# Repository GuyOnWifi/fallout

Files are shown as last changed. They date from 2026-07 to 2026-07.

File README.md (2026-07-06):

# Soup Sports

Nothing like spending your last days on Earth soup! I mean just look at him!! 

## Inspiration

We loved the Wii Sports minigames, but unfortunately as a child, we were only able to play them at that rich friend's house. But now, in the hardware capital of the world, we're able to get microcontrollers tens of times more powerful for dirt cheap. So we thought... why not make a dirt cheap and dead simple Wii Sports controller? 

## What is it? 

It's really just a Xiao ESP32-C3, an MPU 6050 in a wristband form factor. It also has a dongle to receive the wireless transmission! 

## Minigames

### Boxing

Fight soup

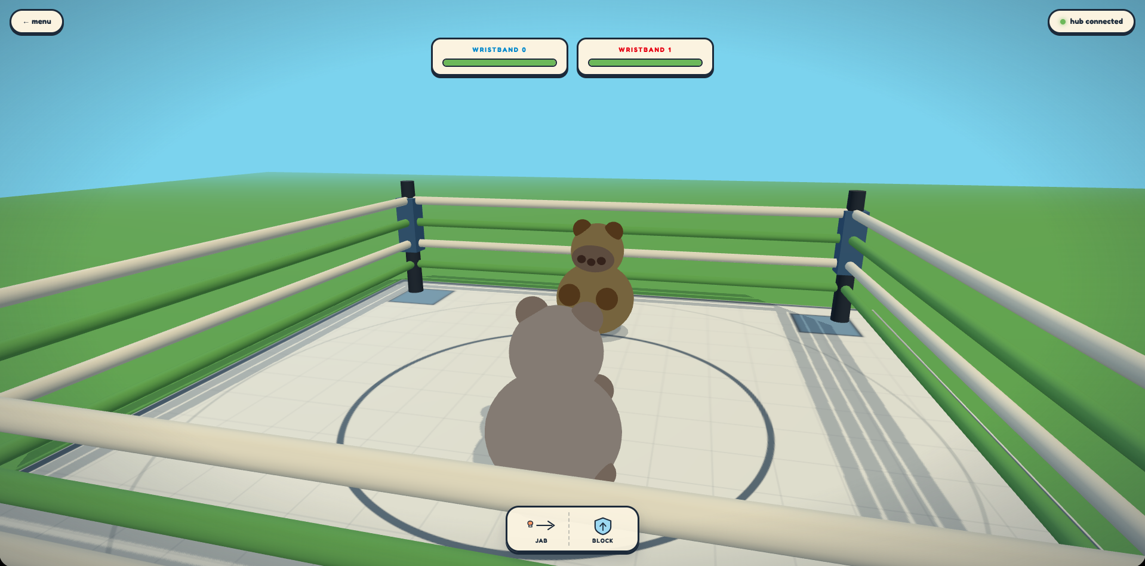
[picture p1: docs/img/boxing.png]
Boxing


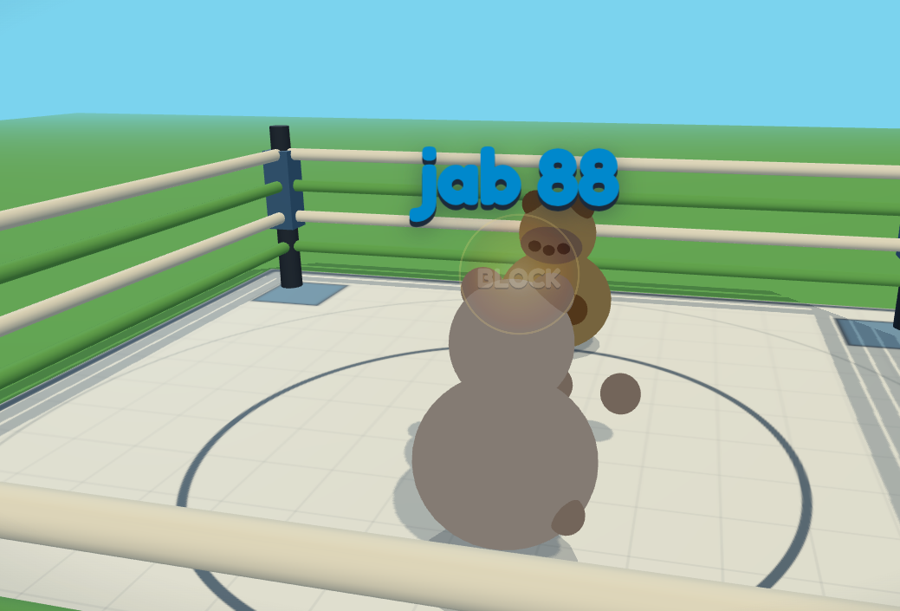
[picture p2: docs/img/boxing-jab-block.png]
Jab Block


### Tennis

Fight each other in this classic ball sport!

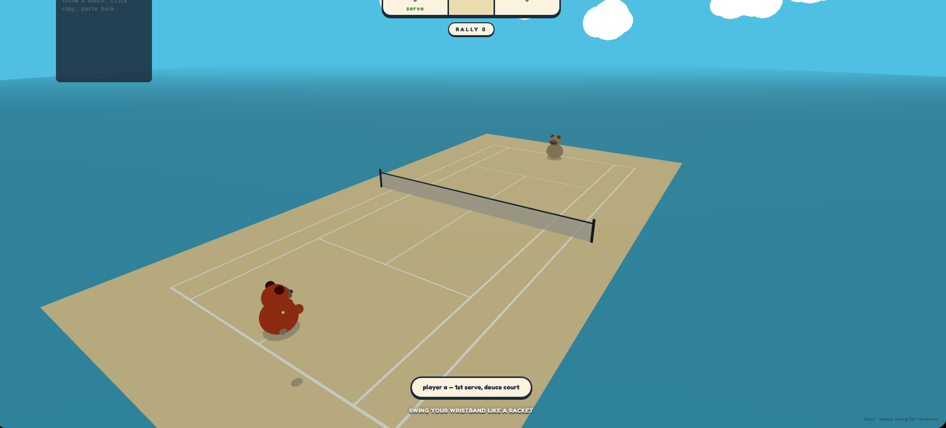
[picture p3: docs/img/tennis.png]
Tennis


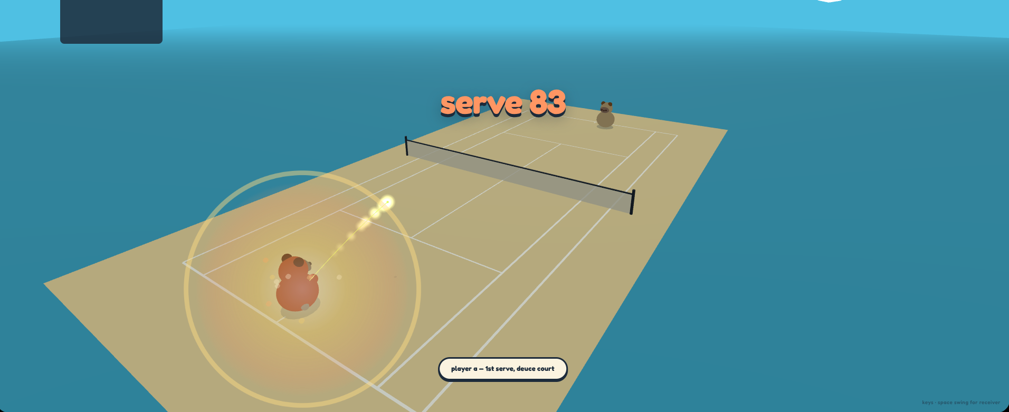
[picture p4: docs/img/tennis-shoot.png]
Tennis shoot


### Badminton

Like tennis but Asian! For those wanting a slower game.

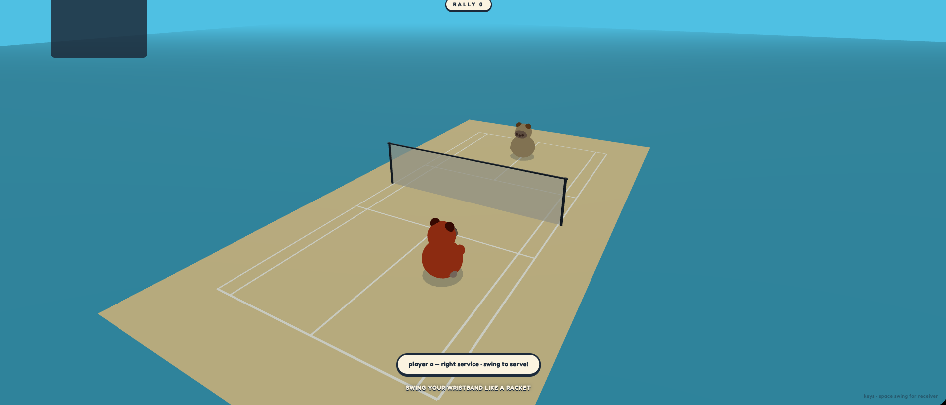
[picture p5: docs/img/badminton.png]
Badminton


### Ping Pong

Like tennis but smaller! For people wanting a quicker reflex game.

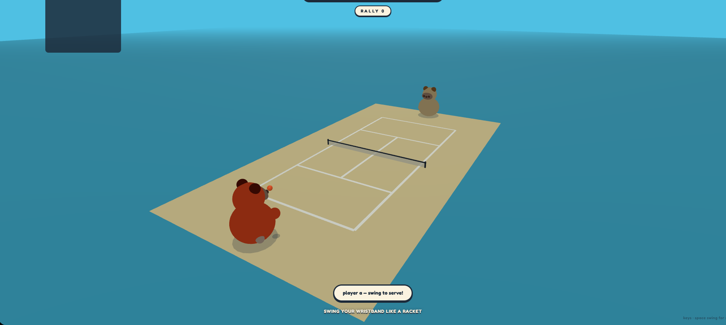
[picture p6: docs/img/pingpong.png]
PingPong


### Soup Ninja

Like fruit ninja but avoid cutting soup D:

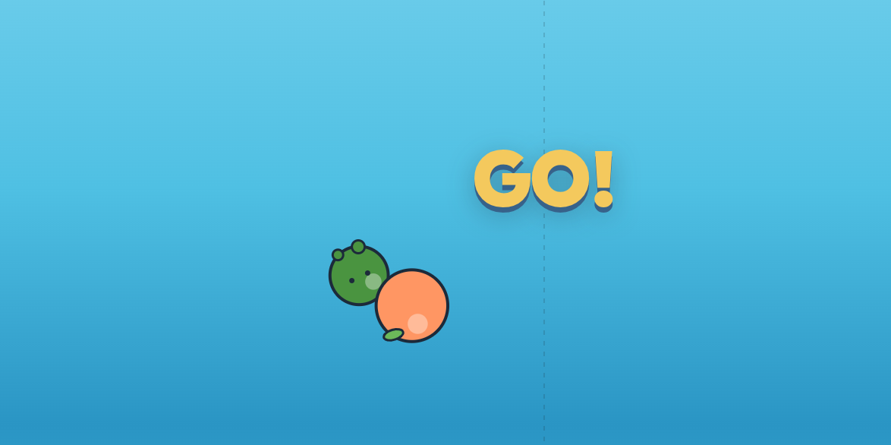
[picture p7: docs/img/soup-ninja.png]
SoupNinja


### Soup Bomb

Try to beat soup as many times before he get angi D:<

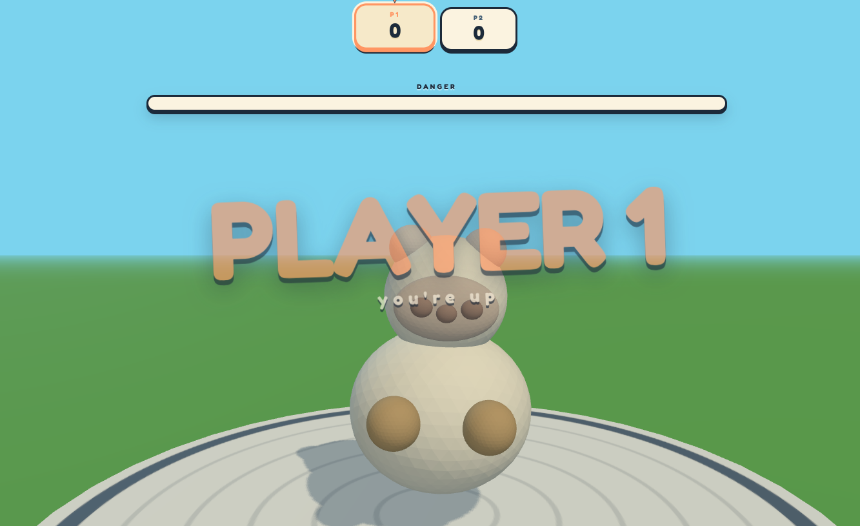
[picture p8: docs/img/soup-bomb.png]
SoupBomb


## Hardware

Soup Sports is played using motion trackers made of a Seeed Studio Xiao ESP32 C3 and an MPU 6050 accelerometer. The tracker is powered using a 1500mAh LiPo cell, managed by the ESP. The tracker is mounted inside a 3D printed case mounted onto the users arm, just below the wrist. It mounts easily using wide zip ties, but is designed for velcro or other reusable methods that insert into the gap and easily stay there.

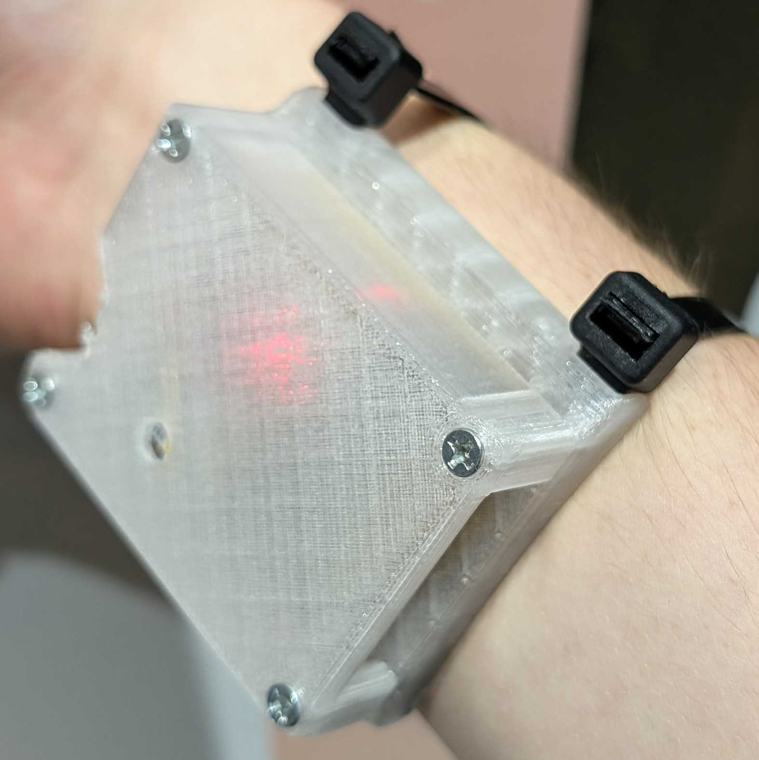
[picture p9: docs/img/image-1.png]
Wristband


https://cad.onshape.com/documents/96dfd435d5d173795bd096b8/w/c7c34e918390195d74f79421/e/89e02144e4e3d73eefe35443

### Wiring 
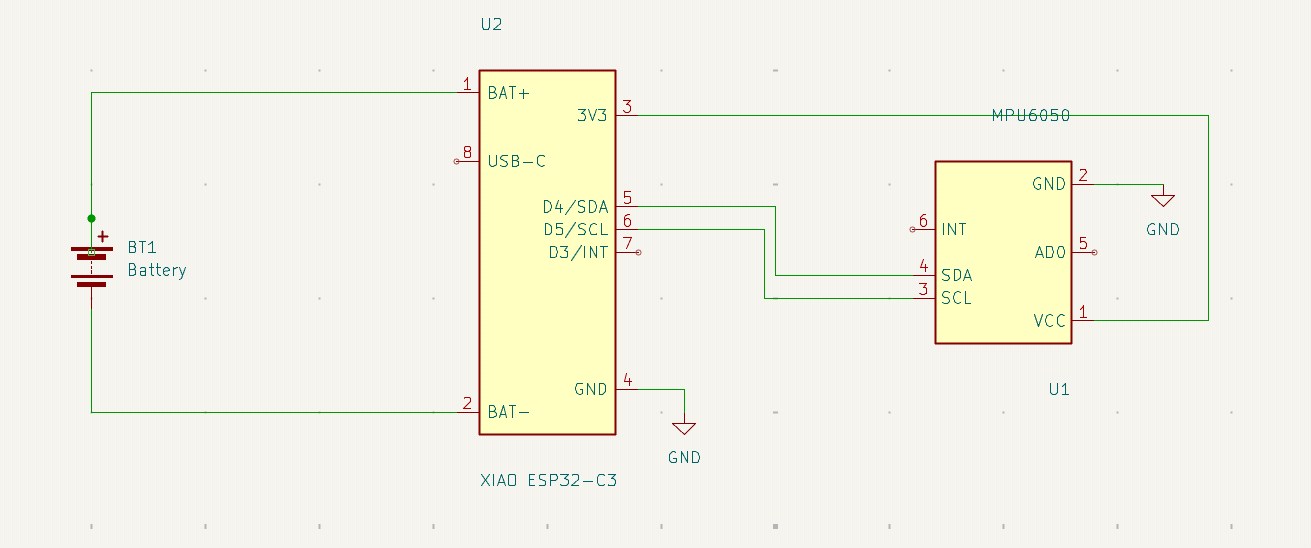
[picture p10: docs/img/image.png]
Wiring


## How to run

We had both the S3 and C3 chips available, so there are two versions of the wrist firmware

```bash
cd firmware
pio run -e wrist    -t upload --upload-port /dev/ttyACM0
pio run -e wrist_c3 -t upload --upload-port /dev/ttyACM0
pio run -e dongle   -t upload --upload-port /dev/ttyACM0

# 2. Start the browser side.
cd ../app
python3 -m http.server 8123
# http://localhost:8123 in Chrome (needs Web Serial, not supported in other browsers)
```

## Zine 
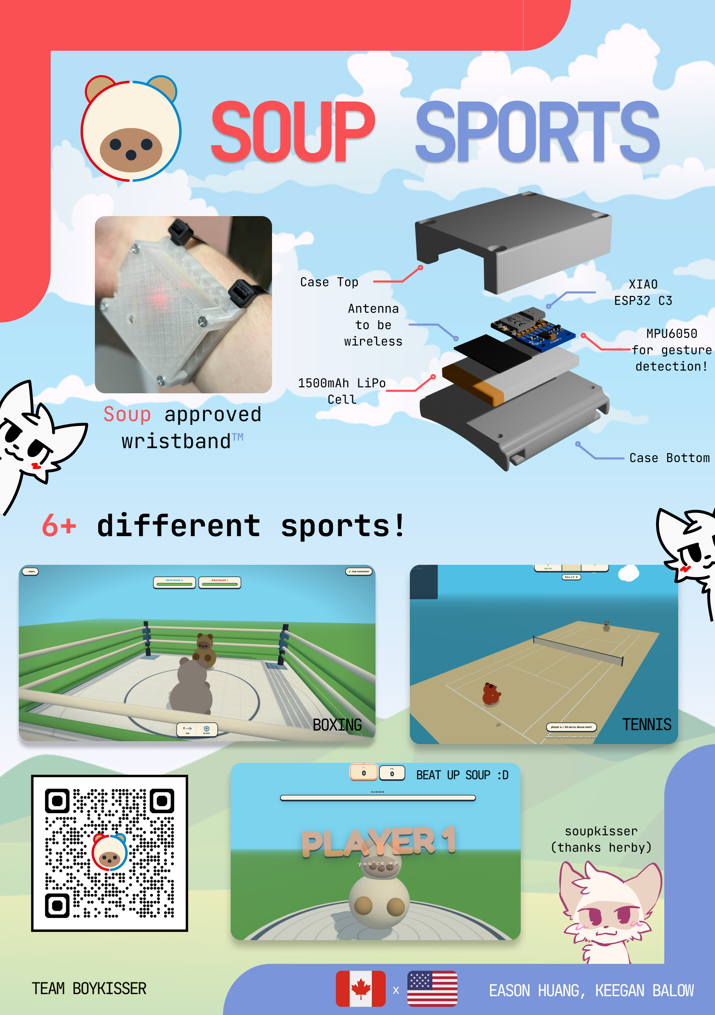
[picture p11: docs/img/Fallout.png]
Zine


Check it out [here](./zine.pdf)!

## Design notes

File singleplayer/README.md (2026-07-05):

# day1 — feature stream + data collection

Goal of day 1: a trustworthy IMU feature stream from one wrist unit, and enough
labeled reps to set classifier thresholds from real numbers instead of guessing.

## Wiring (XIAO ESP32-S3 + GY-521 / MPU6050)

| MPU6050 pin | XIAO pin |
|---|---|
| VCC | 3V3 (3.3V-OUT)  |
| GND | GND |
| SDA | D4 / GPIO5 |
| SCL | D5 / GPIO6 |
| AD0 | floating (0x68) |
| INT/XDA/XCL/FSYNC | leave open |

Board flat against the dorsal (back) side of the forearm, USB-C pointing
toward the elbow. Axis convention documented at the top of the project brief.

## Flash the wrist firmware

```
cd day1/firmware
pio run -e wrist -t upload
pio device monitor -e wrist
```

You should see CSV like:

```
# IMmerseU wrist feature stream
# columns: t_us,ax,ay,az,gx,gy,gz,roll,pitch
12345678,0.12,-0.04,9.79,0.31,-0.10,0.02,-0.24,0.71
...
```

If `Serial` prints nothing, verify `ARDUINO_USB_CDC_ON_BOOT=1` is in
`platformio.ini` (it is) and the device shows up as `/dev/ttyACM0`.

## Collect labeled reps

Close the serial monitor first (only one process can open the port).

```
cd day1/tools
python -m venv .venv && source .venv/bin/activate
pip install pyserial numpy pandas matplotlib

python collect.py --port /dev/ttyACM0 --label jab      --n 20 --out data/jab.csv
python collect.py --port /dev/ttyACM0 --label hook     --n 20 --out data/hook.csv
python collect.py --port /dev/ttyACM0 --label uppercut --n 20 --out data/uppercut.csv
python collect.py --port /dev/ttyACM0 --label block    --n 20 --out data/block.csv
python collect.py --port /dev/ttyACM0 --label idle     --n 20 --out data/idle.csv
```

Press ENTER *at* the moment of the gesture — the tool grabs a window around
that press (~0.2 s before, ~0.4 s after).

## Look at the data

```
python plot.py data/jab.csv data/hook.csv data/uppercut.csv data/block.csv data/idle.csv
```

Prints per-rep peak magnitudes and shows time-series overlays + box plots.
Use those numbers to set the classifier thresholds in the next step.

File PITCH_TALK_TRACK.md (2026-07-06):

# Soup Sports: 90-second talk track

## The pitch (30 seconds)

This is Soup Sports. Wii Sports without the Wii. You strap a wristband on,
you punch, you bowl, you swing a tennis racket, and a cartoon soup mascot
on screen does the same thing back. The wristband is a three-dollar
microcontroller and a one-dollar motion sensor. No console. No camera.
The whole arcade is a browser tab and a USB stick. Two players grab a
wristband, wave, and start playing. The cabinet is cardboard, a phone
mount, and a soup on the front. Costs less than lunch.

## The tech (45 seconds)

The clever bit is how we classify punches. The wristband streams two
hundred samples a second. But sensor axes rotate with your wrist, so a
hook one way looks like a jab another way. Raw axes are hopeless. So on
every sample we low-pass the accelerometer to find which way is down, and
project the reading into up, horizontal, and rotational parts. Those
features don't care how the strap sits. Then a peak-tracking state
machine arms on big motion, watches the peak grow, and commits the moment
the peak starts dropping. That catches the extension of a punch and
ignores the retraction. Thresholds were tuned against twenty recorded
reps per gesture, replayed offline. It runs entirely in the browser, in
about two hundred lines of JavaScript.

## The near future (15 seconds)

Next up is the cardboard cabinet build, cross-cabinet play by adding a
MAC filter in the USB dongle so neighboring machines stop cross-talking,
and a four-player game. The wire format and the pairing scheme already
handle it. We just need the fourth wristband.

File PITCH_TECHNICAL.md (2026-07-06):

# Soup Sports: technical pitch

## The problem we set for ourselves

We wanted Wii Sports without the Wii. The Wii shipped in 2006 with a wired
sensor bar, a proprietary IR camera, and controllers that cost as much as a
console. Almost twenty years later a microcontroller with more compute than
the original Wiimote costs three dollars, a six-axis IMU costs one, and every
laptop in the room already has a display and a browser. The gap between
"Nintendo built a magical living-room sports arcade" and "a hackathon team
could build one over a weekend from parts in a drawer" is finally closed, and
we wanted to prove it. The stretch goal, and the demo gimmick, is a cardboard
arcade cabinet with a phone mount that turns the wristband into a full
standing-up minigame experience: cheap enough that you could deploy them at a
county fair, expressive enough to feel like a real toy.

## The architecture

```
   ┌──────────────┐        ESP-NOW          ┌──────────────┐   USB-CDC   ┌────────────┐
   │  Wristband   │  ─────  broadcast  ───► │  USB dongle  │  ────────►  │  Browser   │
   │  XIAO ESP32-S3│         @ 200 Hz       │  XIAO ESP32-S3│  CSV line   │  Three.js  │
   │  MPU6500 IMU │                         │  (channel 1) │             │  game      │
   └──────────────┘                         └──────────────┘             └────────────┘
          ▲                                                                    │
          │        (multiple wristbands broadcast concurrently;                │
          │         dongle forwards them all interleaved on one port)          │
          │                                                                    ▼
          └─────────── pairing.js maps arm_id → player slot A/B ──────────────┘
```

The wristband is a XIAO ESP32-S3 with a GY-521 breakout strapped to a velcro
band. It samples the IMU at 200 Hz, runs a complementary filter for roll and
pitch, formats each sample as a single CSV line, and shoves it into an
ESP-NOW broadcast. There is no pairing, no association, no TCP, and no
handshake. Every wristband in the room shouts on channel 1; the dongle
listens and forwards whatever it hears out over USB-CDC. The browser opens
that USB port through the Web Serial API, parses lines with a two-lane
dispatcher, and hands per-arm samples to either the classifier (boxing) or
directly into the Three.js scene (bowling, tennis).

The whole radio path is about eight lines of firmware. ESP-NOW does not need
IP, TLS, or authentication, and its broadcast latency measures in single-digit
milliseconds. For a 200 Hz sensor stream this is critical: the round-trip
from a punch peaking to the browser reacting is dominated by browser
rendering, not by radio. The dongle is deliberately dumb. It contains no
game logic, no classification, no state. It is a USB radio and nothing else,
which means we can swap games, retune classifiers, or rewire the whole
browser stack without ever reflashing a board.

## The signal-processing story

The classifier lives entirely in the browser and reads the raw 200 Hz stream.
Its job is to turn a continuous accelerometer and gyro feed into discrete
gesture events for jab, hook, and uppercut, with a confidence-weighted
"power" number attached to each. It runs as a three-state machine, IDLE to
ACTIVE to COOLDOWN, and never touches the sample outside a small fixed
window per gesture.

The interesting piece is that the classifier does not look at raw sensor
axes at all. If it did, a user who mounted the wristband rotated ninety
degrees relative to the training set would see hooks read as jabs and jabs
read as noise. Instead, on every sample we low-pass the accelerometer with
α equal to 0.995 to estimate the sensor-frame direction of gravity, then
project each new accel reading onto that axis and its orthogonal plane. The
result is three orientation-invariant features: `a_up`, the signed
acceleration along gravity; `a_horiz`, the magnitude of acceleration in the
horizontal plane; and `w_mag`, total gyro magnitude. An uppercut spikes
`a_up` positive regardless of wrist roll. A jab spikes `a_horiz` regardless
of yaw. A hook has both, plus rotation about gravity. Once we moved to
gravity-aligned features the classifier stopped caring how the strap sat.

The state machine itself is peak-tracking rather than window-classifying.
We arm on any sample where dynamic accel is above 25 m/s squared or gyro
magnitude is above 400 deg/s, but we do not commit to a classification
until we watch the peak drop below 55 percent of its maximum. That
"post-peak drop" trick lets us catch the extension of a punch (which is the
part of the motion that carries semantic content) while ignoring the
retraction (which happens with high accel but is mechanically the opposite
gesture). Refractory is 850 ms and requires a genuine quiet sample before
re-arming, so a slow hook cannot re-fire on its own snap-back.

Thresholds were not guessed. We built a Python collector that
auto-triggers on peak detection and asks the user for twenty reps per
label, then wrote a Node replay harness that streams those recordings back
through the classifier as if in real time. Every threshold in the file
carries a comment naming the percentile of the training set it clears.
When we retune, we do so against numbers, not vibes, and the replay
harness runs in under a second.

## The multi-controller story

Every wristband derives its `arm_id` at boot from the last two bytes of its
WiFi MAC. That is a single call to `esp_read_mac` in firmware and it means
one binary flashes onto any board without a per-device compile-time flag.
Chip identity is free on the ESP32; forcing developers to remember which
`-DARM_ID=` to pass at build time was a foot-gun that cost us a real hour
of demo-time before we ripped it out.

The browser side pairs arms to players by order-of-shake. When the game
loads, both player slots are empty. The first wristband whose non-gravity
acceleration crosses 12 m/s squared claims slot A. The next distinct
`arm_id` to shake claims slot B. Everything downstream, from the classifier
routing to the on-screen player labels, keys on the abstract player letter,
not on the underlying `arm_id`. This has two nice properties. First, the
pairing UI does not need to know about the hardware at all: it just watches
for two arms to wave, and the physical wristband a player happens to grab
becomes their controller. Second, we can persist the mapping in
`sessionStorage` so that clicking through from the menu to a game preserves
the pairing, but we key the storage under a schema version so that when
the wire format changes (as it did once, when we moved from 0/1 arm_ids to
16-bit MAC-derived ones), stale caches invalidate on the next page load
instead of stranding users on a broken slot.

## What surprised us

- The MPU6050 on our GY-521 breakouts is actually an MPU6500. WHO_AM_I
  reads 0x70, not 0x68. Adafruit's library refuses to talk to it. We
  wrote a forty-line hand-rolled I2C driver against the shared register
  map and it works on both chips.
- The ESP32-S3 will silently swallow every `Serial.println` unless you
  compile with `-DARDUINO_USB_MODE=1 -DARDUINO_USB_CDC_ON_BOOT=1`. There
  is no error, no warning, no log line: the CDC endpoint just does not
  exist. The C3 does not have this trap because it uses a USB-JTAG bridge
  instead of native USB.
- The S3's default WiFi modem-sleep drops about half of a sustained 200 Hz
  ESP-NOW stream. We now unconditionally `WiFi.setSleep(false)` and
  `esp_wifi_set_ps(WIFI_PS_NONE)` at boot. The C3 does not need this,
  which surprised us: its power-save timings evidently interact
  differently with ESP-NOW's peer schedule.
- A pure wrist twist looks like a jab if your trigger is `dynA OR wmag`.
  The wrist rotates fast (huge gyro) and the centripetal accel at the
  IMU is nontrivial. We had to change the trigger from OR to AND on
  horizontal accel, because a translational gesture requires evidence of
  translation, not just of "big motion."
- `sessionStorage` is a persistent lie waiting to happen when your data
  schema changes. Our old two-arm pairing stored `{A: 0, B: 1}`. The new
  scheme uses 16-bit ints. Old caches meant a shake on wristband #2
  fell through slot A (already assigned to 0, a value no live wristband
  produced) and slot B stayed permanently empty. We bumped the storage
  key from `v1` to `v2` and the bug disappeared.

## What's next

The cardboard arcade cabinet is the next physical build. A phone mount
inside a folded shroud gives the wristband experience a fixed camera and
a two-hand posture that reads as "arcade cabinet" instead of "person
staring at their phone." Cross-cabinet play is a small firmware change:
add a MAC filter in the dongle so it only forwards packets from the two
wristbands paired to that machine, and neighboring cabinets stop cross-
talking. Beyond that, the classifier has room for a four-player game (the
data plane already handles multiple `arm_id`s cleanly), and the natural
target is a mascot-based tennis doubles or a bowling relay. The wire
format, the pairing scheme, and the classifier all extend without a
rewrite. The only thing standing between us and that game is the cardboard.

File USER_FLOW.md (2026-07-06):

# Soup Sports — user flow wireframes

Cold-start to first-punch, PvP session, and recovery paths.
Text wireframes so we can iterate on the flow independently of visual fidelity.

---

## Flow 1: Cold-open to first game (one player)

```
┌──────────────────────────────┐
│ landing page                 │
│                              │
│  SOUP SPORTS                  │
│  wristband sports arcade     │
│                              │
│  ┌──────┐   ⇄   ┌──────┐    │  slot A + B, empty
│  │  A   │       │  B   │    │  "waiting for a wave"
│  │ ...  │       │ ...  │    │
│  └──────┘       └──────┘    │
│      [ connect hub ]         │  primary CTA
│                              │
│  ┌───┐┌───┐┌───┐┌───┐        │  game grid — clickable but
│  │Box││Bwl││Tns││Fsh│        │  greyed / soft until a slot
│  └───┘└───┘└───┘└───┘        │  is claimed
└──────────────────────────────┘
      │
      │  user clicks [ connect hub ]
      ▼
┌──────────────────────────────┐
│ browser port picker (Chrome) │
│  > /dev/ttyACM0              │
│  > /dev/ttyACM1              │
└──────────────────────────────┘
      │
      │  user picks the dongle
      ▼
┌──────────────────────────────┐
│ landing — hub connected      │
│                              │
│  slot A: waiting for wave    │  ← dot pulses gold
│  slot B: waiting for wave    │  ← dot pulses gold
│                              │
│  waiting on wristband        │  small helper text
└──────────────────────────────┘
      │
      │  user waves wristband
      ▼
┌──────────────────────────────┐
│ landing — slot A claimed     │
│                              │
│  slot A: wristband 17812     │  ← letter BLOB shakes
│         · connected          │     with wristband
│  slot B: waiting for wave    │
└──────────────────────────────┘
      │
      │  user clicks a game card
      ▼
┌──────────────────────────────┐
│ game (e.g. bowling)          │
│                              │
│  fallback: "single-player    │
│   mode — pair a second       │
│   wristband on the menu      │
│   for versus"                │
└──────────────────────────────┘
```

## Flow 2: Two-player pair-up

```
LANDING → both slots empty
        ↓  player A waves
LANDING → slot A claimed (letter shakes)
        ↓  player B waves
LANDING → slot B claimed (letter shakes)
        ↓  either player clicks a game card
GAME    → PvP mode automatically active

     if the user wants to swap sides
        ↓  click ⇄ button between the cards
LANDING → A and B swap arm_ids
        ↓  persists across game switches (sessionStorage)
```

## Flow 3: PvP boxing round

```
BOXING game-active

┌───────────────────────────────────────┐
│ HUD-p1 (player A) │ HUD-p2 (player B) │  HP + stamina + combo bars
│ ▮▮▮▮▮▮▮▮▮▮ 100    │    100 ▮▮▮▮▮▮▮▮▮▮ │
├───────────────────┼───────────────────┤
│                   │                   │
│    soup A         │    soup B         │  facing each other
│    (attacks →)    │    (← attacks)    │  fixed camera
│                   │                   │
└───────────────────┴───────────────────┘
        │
        │  A throws a jab
        ▼
    Player A's mascot animates jab, ~105ms later
    the impact fires:
      · Player B's HP -= dmg
      · Player B's mascot plays hit_jab reaction
      · Screen shakes, sparks, hit-flash
      · Combo counter for A ticks up

        │  either player's HP hits 0
        ▼
    KO fires. Camera pushes in on the loser
    (state.koLoser = whichever fighter's HP <= 0)
    Banner announces "player A wins" or B.
    Game freezes.
        │
        │  reload the page
        ▼
    Fresh match. Pairing persists via sessionStorage.
```

## Flow 4: Wristband disconnection recovery

```
GAME running, both slots live
        ↓  a wristband loses power (LiPo dies, brownout, out of range)
GAME → last-seen timer for that arm_id passes 500ms
        ↓
GAME → HUD's slot pill goes back to "idle"
        ↓  wristband comes back (LiPo swap, replug)
GAME → next sample lands under old arm_id → slot resumes "connected"
        ↓
GAME resumes without re-pairing (sessionStorage still holds the assignment)
```

## Flow 5: Session reset (used rarely, e.g. after a hard flash)

```
LANDING
        ↓  click [ reset pairing ] (planned button)
LANDING → sessionStorage cleared, both slots wiped
        ↓  wave a wristband
LANDING → first shake claims A again
```

## Cross-flow: what breaks and how the UI shows it

| Failure mode | Where user sees it |
|---|---|
| Dongle unplugged | "connect hub" pill reappears with "hub disconnected" text. |
| Dongle plugged but no traffic | Slots stay on "waiting for a wave" indefinitely — no progress. |
| One wristband broadcasts, other silent | One slot claims, other keeps pulsing gold. Games hint "pair both bands for versus." |
| Both wristbands broadcast but same arm_id | Only slot A claims. Slot B never fills. (Only possible if MAC collision — astronomically unlikely.) |
| WebSerial not available (Firefox)| Landing shows a hard error: "Web Serial not available. Use Chromium." Everything else is inert. |

## Copy inventory (for consistency)

| Screen state | Text |
|---|---|
| slot empty, no hub | waiting for a wave |
| slot empty, hub live | waiting for a wave |
| slot filled, sample fresh| wristband N · connected |
| slot filled, sample stale| wristband N · idle |
| both slots filled | (swap button enabled — no explicit label needed) |
| KO fired in boxing | KO — player A wins  /  KO — player B wins |
| game won in tennis | game A  /  game B  /  set A  /  set B |
| 10th frame closed | player A total: 132 · player B total: 118 · player A wins|

## Open UX questions we haven't resolved yet

- Between games: do you go back to the menu to switch, or is there an in-game shortcut? (currently: back button to menu — one extra click)
- Rematch: after a KO or game-end, do you get a "play again?" pill or hard-reload the page? (currently: hard reload)
- Names beyond A / B: do the players want to type real names, or is A / B enough? (leaning: A / B, keep it fast)
- Winning ceremony: does the winning mascot cheer? Does the loser stay crumpled? (boxing does the crumple; tennis and bowling don't celebrate yet)

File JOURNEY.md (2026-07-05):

# IMmerseU — build journey

Chronological log of what we hit and how we got past it. Written for the next
person (probably future us) who needs to know *why* the code looks the way it
does. Everything below actually happened.

---

## Day 1 — feature stream, classifier, first demo

### Wiring the MPU6050

Started with a GY-521 MPU6050 breakout to a XIAO ESP32-S3.
Verified default pinout: **SDA → D4/GPIO5, SCL → D5/GPIO6, VCC → 3V3-OUT, GND**,
AD0 floating (I²C addr `0x68`). GY-521 has onboard pull-ups so no extra resistors.

### First flash: linker failure

First PIO build failed with `undefined reference to setup / loop`. Cause:
default `src_dir` for a PIO project is `src/` next to `platformio.ini`, but I'd
put main.cpp at `wrist/src/main.cpp`. Fix: add `[platformio] src_dir = wrist/src`
to `platformio.ini`. Two-line change, ten minutes lost.

### Second flash: MPU6050 not found

Firmware built and Serial worked, but `Adafruit_MPU6050::begin()` failed. Added
an I²C bus scan — device answered at `0x68` (so wiring was fine and power was
fine), but the library refused it. Read WHO_AM_I directly and got **`0x70`**,
which is **MPU6500, not MPU6050**. This is a super common bait-and-switch on
cheap "MPU6050" breakouts; the vendor swaps the chip and keeps the silkscreen.

Adafruit's driver strictly checks WHO_AM_I so it won't touch a 6500. Options:
find a 6500-compatible library, or hand-write a minimal driver. MPU6050 and
MPU6500 share the same register map for basic accel+gyro, so I dropped the
Adafruit deps entirely and wrote ~40 lines of raw `Wire` code. Works with either
chip and now the firmware doesn't have library churn to deal with.

### Feature stream working

Complementary filter, 200 Hz, `t_us,ax,ay,az,gx,gy,gz,roll,pitch` CSV over USB
CDC. Two config gotchas worth remembering:

1. `-DARDUINO_USB_CDC_ON_BOOT=1` is mandatory on the S3 — without it, `Serial`
   silently prints nothing over USB-C on PIO, no error.
2. Adafruit's lib reports gyro in **rad/s** — the raw MPU register lets you
   read directly as `raw / 16.4 = deg/s` at ±2000 dps, which is what we want
   for human-readable thresholds. We use deg/s throughout.

Sanity checked at rest: `|a| ≈ 9.8`, gyro noise 1–2 dps. Clean.

### Data collector, take 1: manual ENTER

First collector was cmdline-driven — "press ENTER at the moment of the punch."
User couldn't do that while actually throwing punches. Reasonable feedback.

### Data collector, take 2: interactive prompts

Rewrote with a menu, port auto-detect, per-rep peak readout. Still ENTER-per-rep.
Still not usable — punching *and* pressing ENTER at the same time is a bad ask.

### Data collector, take 3: auto-trigger

Third rewrite: 3-2-1 countdown, then a 6-second arm window where the tool
watches for a motion spike, auto-captures ±200/400 ms around the peak, and
re-arms after a 600 ms refractory. Separate **hold-mode** path for `idle` and
`block` (records a 1 s window and rejects if the user wobbled). This is the
version that got used.

Also added gesture hints (what the physical motion actually is) — the model
kept describing "punch" without saying whether the wrist should be palm-up or
palm-down, and that ambiguity would kill classifier consistency.

### Building the Three.js demo

Started with a plain scene. User pointed at kevinyhe/eureka-hacks-2026 and
asked for that visual style. Pulled the reference project's key files, absorbed
the design language, and rebuilt: black bg, uppercase HUD, health/stamina/combo
triple-bar stack, red/blue color coding, hit-confirm (burst + expanding ring +
damage number), full-screen red hit flash, gray gridded ring floor with red
and blue corner pads, striped ropes at four heights, camera shake on hit,
title screen that fades on connect.

Kept the reference's `.game-active` body flag pattern — everything HUD-related
fades in when the wrist connects.

Dev shortcut: press `j` / `h` / `u` to fake a gesture and preview the FX
without the hardware — turned out to be very useful for iterating on visuals
while the sensor was being re-mounted.

### First classifier + verification via replay

Wrote a threshold classifier (state machine: IDLE → ACTIVE → COOLDOWN) that
consumed the same CSV lines the browser would receive over serial. Built a
`replay.mjs` harness that feeds recorded reps back into the classifier at fake
time — no hardware needed for regression testing. First result on real data:
**19/20 jab, 16/20 hook = 87.5%**. Tuned the hook vs jab discriminator to use
the gx/ax ratio (rotation dominance rather than a fixed gx threshold) → **18/20
jab, 18/20 hook = 90%**.

Also useful: the replay caught a classifier state-machine bug immediately —
first version double-fired on retraction. Increasing refractory time and
requiring a "quiet" plateau before classifying fixed it.

### The wrist-rotation problem

User rolled the sensor mid-play and everything broke. That's inherent to
sensor-frame classification: `ax` means "the IMU's own +X axis," and if the
chip rotates, the meaning of that axis changes with it.

**Approach the reference project uses:** iPhone CoreMotion gives them a fused
quaternion (accel + gyro + mag) → they get world-frame linear acceleration
with gravity subtracted for free. Rotating the phone doesn't affect the
detector because features are computed in a world-anchored frame.

**We can't do that directly** — MPU6500 has no magnetometer, so we can't
recover absolute yaw. But we don't need full world orientation for boxing.
Gravity gives us two axes for free, and boxing gestures are body-relative, not
compass-relative. So:

- Low-pass the accel to estimate gravity direction in the sensor frame.
- Decompose every sample into `a_up` (along gravity), `a_horiz` (magnitude in
  the horizontal plane), and gyro components `ω_yaw` (about gravity),
  `ω_horiz` (about horizontal). All four are invariant to wrist rotation
  about horizontal axes (supination/pronation), which is the dominant kind of
  wrist rotation a boxer does.

Yaw about gravity (arm sweep) is still unrecoverable — but for gesture
*magnitude* features we don't care about direction, just amount, so it doesn't
matter.

### The magnetometer question

User asked whether buying a mag would help. Answered no for this hackathon:

- The rotation flavor that breaks us (forearm supination/pronation) is already
  fixed by gravity alignment, mag adds nothing there.
- The rotation flavor a mag *does* fix (yaw about gravity) doesn't correspond
  to a real boxing problem — a jab thrown facing north and a jab thrown facing
  east are both "jabs," not "north-jabs."
- Magnetic environments at hackathon venues are hostile (laptops, motors,
  iron chair frames, nearby LiPo) — hard-iron / soft-iron calibration would
  need redoing every time we move the assembly.
- A BNO055 (which does 9-DOF fusion in hardware and outputs quaternions) is
  the buy if we ever do this properly. For tonight: gravity align + collect
  more data across mount orientations.

### Verifying gravity-aligned features on real data

Ported the classifier to gravity-aligned features. First replay result:
everything classified as `overhand` — LPF hadn't converged because the replay
warm-up fed fake `(0, 0, +g)` "quiet" samples, but the recorded reps' actual
gravity direction was different. Fed the rep's own first sample as warm-up
seed instead, and used **median accel** as the per-rep gravity reference (the
first-200 ms "pre-trigger" window turned out to still contain punch wind-up,
so a mean was contaminated, but the median rejects the transient spike).

With correct gravity, the gravity-aligned features gave weaker jab/hook
discrimination (~70%) than raw-axis (90%). That's the fundamental tradeoff:
the useful signal for jab-vs-hook lives in *forearm-frame* rotation (gx =
forearm long-axis roll), and forcing everything into gravity frame throws
some of that away.

### JAB-ONLY mode for the live demo

Sensor mount had drifted between old data collection and live test — old
thresholds no longer applied. User collected fresh jab reps. Instead of
guessing hook thresholds without hook data, short-circuited the classifier
to fire `jab` on any punch-like spike. Isolates trigger logic from
discrimination — the game reacts to a real punch every time.

### False positive on wrist twist alone

Even in JAB-ONLY mode: just rotating the wrist fast (no arm movement) fired
a jab. Cause: my sanity gate accepted `dynA >= 18 OR wmag >= 300`. A pure
wrist twist has high gyro and low translation, so `wmag` alone was enough.

Right answer, same one the reference project uses implicitly: **a jab requires
translational evidence, not just any motion.** Changed the condition to require
`horiz >= 15 AND dynA >= 18` — actual gravity-subtracted horizontal linear
accel. Pure rotation produces almost no horizontal accel (the IMU on the
forearm is near the axis of rotation during a wrist twist, so centripetal
accel is negligible), so it no longer fires.

Same principle will separate hook from jab when we get there: hook has both
translation (arm sweeps through an arc → centripetal accel ~40 m/s²) and
rotation, jab has translation without much rotation. The reference project
does the same distinction on their CoreMotion `userAcceleration` stream.

### False positive at rest

Also: the classifier was firing when the sensor sat still. Cause: the ARM
threshold was low enough that idle noise could briefly clear it, enter
ACTIVE, and produce a valid classify path if the ACTIVE window ever saw a
big-enough peak. Fix: added a peak-sanity gate (`MIN_PEAK_DYNA=18`) that
drops silently if the peak of the ACTIVE window never actually built to a
real punch magnitude.

---

## Things worth remembering for day 2

- **The bait-and-switch on IMU chips is a real thing.** Read WHO_AM_I first,
  don't trust the silkscreen. Rolling a minimal driver is cheaper than
  library-shopping.
- **`ARDUINO_USB_CDC_ON_BOOT=1` on S3, always.** No error, just silent.
- **`replay.mjs` earned its keep** — it caught the state-machine double-fire
  and the LPF warm-up bug without needing hardware. Any classifier tweak from
  here on should be verified against recorded reps first.
- **Sensor-frame features are fragile.** Gravity-aligned features are more
  robust but discriminate less cleanly. The right long-term answer is a
  learned classifier with reps collected across multiple mount orientations,
  not more threshold tuning.
- **The "big rotation but no translation" case tripped us twice** — first as
  the wrist-rotation robustness problem, then as the false-positive on twist
  alone. Both times the fix was to require *translational* evidence
  specifically. Anytime we add a new gesture, ask: what's the translational
  vs rotational signature, and does the trigger require the right kind?
- **Don't buy hardware to fix a data problem.** The mag question was the
  clearest example — but the same principle applies to a bigger LiPo, a
  fancier IMU, a BNO055, etc. Buy for real hardware limits, not to paper
  over a software gap.
- **Follow the "ugly but complete" plan.** The wrist → ESP-NOW → dongle →
  serial path is still not tested; that's the biggest lurking risk and
  should be next before more polish.

---

## Day 3+ — the pivot to Soup Sports

Day 3 opened with the "wireless + polish" plan and closed on a completely
different project. Documenting every wrong turn so future us doesn't retrace
them.

### The wireless cut worked

`day1/firmware/*` was tethered USB CSV. Ported into `day3/firmware/src/` with
Mark's `esp_now_broadcast` pattern, split into three PIO envs
(`wrist_right`, `wrist_left`, `dongle`) sharing one src tree via
`build_src_filter`. Broadcast (`FF:FF:FF:FF:FF:FF`) — no MAC configuration.
Wire format got a leading `arm,` field so both bands multiplex through one
dongle to one serial port. `ArmDispatcher` on the browser side routes
per-arm samples to per-arm `Classifier` instances. Backwards-compat: 9-field
day1 lines are treated as arm 0. Everything's still one line of ASCII CSV
so `pio device monitor` remains a useful diagnostic.

**Payoff:** the day1 browser code kept working unchanged. The classifier
tuning inherited from day1's replay harness. Cost: ~2 hours.

### The "add SpaceEngine gesture navigation" trap

Mark had a sibling project driving SpaceEngine via wrist gestures. Ostensibly
themed to the hackathon prompt ("world is ending → explore the universe").
The conversation this morning circled that direction for an embarrassing
number of hours. It failed for reasons worth remembering:

1. **SpaceEngine is paid, Steam-only, Windows-only, closed-source.** Every
   demo pivot became "and it also depends on this one specific software
   nobody on the team owns."
2. **Gesture-as-command feels gimmicky.** Sweep-left = "prev waypoint" is a
   worse keyboard, not a physical experience. VR feels immersive because
   your hand IS the thing; a gesture-remote is just a remote.
3. **The user correctly identified this each time.** I kept proposing
   variants — cinematic overlay, cockpit build, joystick emulation for
   free-fly mode, wristband-as-Wii-remote — and each got rejected for the
   same underlying reason: it's dressing on a fundamentally passive demo.

Also considered and rejected: **open-source SpaceEngine alternatives**
(Gaia Sky, OpenSpace, Celestia). Any of them are technically workable — Gaia
Sky in particular has documented gamepad + Python-scripting APIs — but the
core gesture-as-remote problem is unchanged by swapping the software behind
the visuals.

**Lesson: propose direction pivots, don't dress up an existing direction as
a new one.** Every SpaceEngine variant I proposed was the same demo with a
different wrapper. The user's frustration was warranted.

### The pivot that landed: Wii Sports (Soup Sports)

The correct pivot was to a demo where **movement IS the mechanic**, not the
control layer. Boxing was the anchor (already 80% done in `day1/`). Then
bowling, tennis, baseball — each with a distinct swing/timing gesture,
each fun in 30 seconds, each cardboard-cabinet-with-phone-mount ready.

The user rebranded it "**Soup Sports**" once he had a mascot design he
liked. The mascot is Soup — a chubby cream cat-shape built from stacked
spheres, based on an emoji he liked. Post-apocalyptic Wii Sports vibe.
Every character in every game is Soup: opponent boxer is Soup, bowling
pins are 10 tiny Soups, tennis CPU is Soup, baseball pitcher is Soup.

**Lesson: the mascot became the pitch.** Before Soup, this was "wristband
boxing." After Soup, it's a memorable brand judges will recognize on a
poster. The mascot itself was 90 minutes of work in `soup/` (OpenSCAD
first, then Python spheres+PBR materials via trimesh). Enormous ROI.

### Four minigames in one afternoon (parallel agents)

Once the direction was locked, delivery was fast. I spun up **three
parallel general-purpose agents** to finish bowling, build tennis, and
build baseball simultaneously. Each was scoped to a single HTML file so
no merge conflicts. Then a second parallel pass — **four agents at once** —
did the Soup Sports re-skin: cyan sky background, cream+ink HUD panels,
chunky pill buttons, and the mascot loaded via `GLTFLoader` per-game with
procedural per-frame animation.

**Lesson: parallel agents are worth it when the boundaries are file-level.**
Each agent had a clear "read A/B/C, write only D" contract. No shared
mutable state, no cross-agent merges. Both passes (game-build + Soup pass)
finished inside 15 minutes wall-clock.

### The "no undo undo WHAT HAVE YOU DONE" moment

A follow-up agent added tall bat ears, eye sparkles, blush cheeks, a smile,
and feet to the mascot. User said "no undo undo WHAT HAVE YOU DONE" and it
got reverted. Current sober Soup is intentional. **Do not add facial
detail or limbs to Soup unless explicitly asked.**

Also worth remembering: the user was told the game agents could use
animation clip names like `idle`, `hit_light`, `hit_heavy`, `ko`,
`cheer`, `wave`, `walk`, `bowling_pin_fall`. **None of these exist as
actual `AnimationClip`s in the GLB.** Soup has no rig. Every animation
is procedural per-frame math in the game files — position bobs,
rotation.z tweens, material color flashes. Cheaper than a rig and looks
fine on a limbless character. HANDOFF.md has the recipes.

### JAB-ONLY MODE and what's still open

The classifier was tuned on day1 data collected with a specific arm mount.
When the wireless firmware moved the sensor, thresholds drifted. Instead of
retuning discriminators without fresh data, I short-circuited `_classify()`
so any valid trigger fires `jab`. Bowling/tennis/baseball don't use the
Classifier (they consume raw samples), so this only affects boxing's hook
vs uppercut discrimination. To restore multi-class: collect fresh reps for
each label on the current mount, run `replay.mjs`, re-enable the multi-class
branch in `_classify()`.

### Things worth remembering from day 3

- **Direction pivots need to be real pivots, not resurfaced versions of
  the rejected direction.** Wristband-as-joystick was a resurface. Cardboard
  cabinet was a resurface. Cockpit was a resurface. Wii Sports was a real
  pivot.
- **Brand is the demo.** Soup Sports became memorable the moment the
  mascot showed up in every game with a consistent palette. Before that,
  it was four decent minigames with no through-line.
- **Parallel agents at file-level scope work.** ~15 min for four polish
  passes across four game files. Would have been ~2 hours sequentially.
- **The "cardboard cabinet with phone mount" hardware bit is still
  unbuilt.** All demo polish is web-side. The physical build (cabinet, CAD,
  wristband strap, LiPo, vibration motor) is the biggest remaining risk.
  Software floor is ready; hardware floor is not.
- **Repo hygiene:** committed via `.gitignore` early. `.pio/` and
  `managed_components/` never entered the tree; final push was 1.6MB / 40
  files. Mark's separate repo was `rm -rf`'d out of the tree with his
  training-tools sibling folder preserved separately.

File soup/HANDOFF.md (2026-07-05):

# Soup mascot — handoff to the game agent

## What this is

Soup is a chubby cream cat-adjacent character built from overlapping spheres.
Modeled after an emoji the user shared. He's the mascot for **everything** in
the day3 games — opponent, player, bowling pins, referee, crowd. Retint per
role.

The canonical deliverable is `day3/app/assets/mascot.glb` (also mirrored here
as `soup.glb`).

Preview: `soup_render.png` (matplotlib preview — mesh triangulation is a
renderer artifact, not in the actual model).

Reference art: `refs/soup_reference_sitting.png` (the other emoji refs the
user shared are no longer in the image cache; describe him as "chubby cream
cat, two stacked balls, small ears, taupe face-mask with two dark oval eyes
and a matching-sized dark nose, tiny paws in front").

## Files in this folder

| File | What it is |
|---|---|
| `build_soup.py` | Source of truth. Builds the mascot from spheres and exports GLB + STL. Tunables at the top. |
| `render_soup.py` | Matplotlib preview renderer. Imports `build_soup`, reads `parts`, writes `soup_render.png`. Use for quick visual iteration. |
| `soup.glb` | Current export (same file as `day3/app/assets/mascot.glb`). |
| `soup.stl` | Geometry-only fallback (no colors, no material slots). Useful for 3D printing. |
| `soup.scad` | Early OpenSCAD version, superseded by `build_soup.py`. Kept for reference only. |
| `viewer.html` + `shoot.mjs` | Local three.js viewer + a Node screenshot script. Serve `python3 -m http.server 8765`, open `http://localhost:8765/viewer.html`. `shoot.mjs` needs `playwright` installed (npm was uncooperative in the dev sandbox — matplotlib was the working preview path). |
| `refs/` | Reference art from the user. |
| `HANDOFF.md` | This file. |

## Scene graph (the important part)

`mascot.glb` is a glTF Scene with **six named nodes**, each with its own
`PBRMaterial` (metalness 0, roughness 0.85). Material name matches node name.

```
mascot.glb (Scene, z-up, mm units, feet at z=0)
├── body        baseColor cream       (240, 225, 210)   torso + head sphere
├── ears        baseColor cream_dark  (210, 185, 165)   two ear bumps on top of head
├── face_patch  baseColor taupe       (170, 138, 115)   darker oval mask on face
├── eyes_nose   baseColor brown_dark  ( 95,  62,  50)   two eyes + nose blob
├── paws        baseColor cream_dark  (210, 185, 165)   two little arms on front of body
└── tail        baseColor cream_dark  (210, 185, 165)   nub off back-left of body
```

Node names are safe to use in `scene.getObjectByName(...)`. Material names
match. Body and head are one merged node ("body") — if you need to bob the
head independently, split it out in `build_soup.py` (see "Modifying" below).

## Retinting per instance (Three.js)

```js
const gltf = await loader.loadAsync('assets/mascot.glb');
const soup = gltf.scene;

// materials are shared by default — clone before mutating if you're
// spawning multiple instances that need different tints
soup.traverse(o => { if (o.isMesh) o.material = o.material.clone(); });

soup.getObjectByName('body').material.color.setHex(0xff8888);
soup.getObjectByName('paws').material.color.setHex(0xff8888);
// leave face_patch / eyes_nose alone unless you want a themed variant
```

For dozens of pins, load once and `SkeletonUtils.clone` (or plain
`scene.clone(true)`) per instance — cheap.

## Coordinate system + orientation

- **Units:** millimeters. Height ~122mm. Scale down in Three.js if you want
  meters (`soup.scale.setScalar(0.008)` puts him at ~1m tall).
- **Up axis:** +Z. Three.js is Y-up. On load, rotate the root:
  `soup.rotation.x = -Math.PI / 2;`
- **Facing:** his face points toward **−Y** in model space. After the
  Y-up flip that becomes **+Z** (toward camera in a default Three.js scene).
  You'll probably want to flip him with `soup.rotation.y = Math.PI` if he
  needs to face −Z.
- **Pivot:** at his feet (z=0 in model space, y=0 after the flip). Drop him
  on the floor without offset math.

## Poly count

~7k triangles across all nodes combined. Fine for 10+ instances.

## The animation situation

**No rig. No animation clips. Zero.** He's a static bag of spheres.

The user was told the game agent could use `idle`, `hit_light`, `hit_heavy`,
`ko`, `cheer`, `wave`, `walk`, `bowling_pin_fall`. **None of these exist in
the GLB.** `AnimationMixer` will find no clips.

### Recommended workaround: procedural animation

Since soup is a chubby ball, procedural per-frame transforms read fine —
often better than a bad rig on a limbless character. Suggestions:

- **idle:** `soup.position.y = baseY + Math.sin(t * 2) * 0.02;` (gentle bob)
  Optional: `soup.scale.y = 1 + Math.sin(t * 2) * 0.03;` for a squish-breathe.
- **hit_light:** GSAP or manual tween — shake `soup.position.x` ±0.05 for
  120ms, flash `body.material.color` red for 100ms.
- **hit_heavy:** bigger shake + a quick backwards lean via `rotation.x`.
- **ko:** tween `rotation.z` to ±Math.PI/2 over 400ms, then drop
  `position.y` to floor. Spawn a couple of star sprites.
- **cheer:** two quick vertical hops (position.y sine burst) + small
  `rotation.z` wiggle.
- **wave:** rotate the `paws` node ±0.3 rad around z at ~4Hz for 800ms.
- **bowling_pin_fall:** apply an angular velocity around a horizontal axis
  perpendicular to the impact direction, integrate until pin hits the floor.
  Cannon-es / Rapier physics is easier than hand-rolled for the pin case.

If you want, ask the user to have me add a `mascot-anim.js` helper exporting
`idle(mesh, t)`, `hit(mesh, {heavy})`, `ko(mesh)`, `cheer(mesh)`, etc. — it
would live in `day3/app/` and be a tiny ES module. Wasn't built yet because
the user hadn't asked for it.

## Modifying the mascot

Edit `build_soup.py` and rerun:

```bash
cd soup/
python3 build_soup.py                                    # rebuild GLB + STL
python3 render_soup.py                                   # preview
cp soup.glb ../day3/app/assets/mascot.glb                # ship
```

Tunables at the top of `build_soup.py`: `BODY_R`, `HEAD_R`, `HEAD_DZ`,
`EAR_R`, `ARM_R`, `TAIL_R`, `SUBDIV`, and the palette constants
(`CREAM`, `CREAM_DARK`, `TAUPE`, `BROWN_DARK`).

To split head from body (useful for head-nod animations): move the head
sphere out of `body_parts` into its own `head_parts` group and add a
`scene.add_geometry(group(head_parts, CREAM, 'head'), node_name='head',
geom_name='head')` line. Then the head has its own node in the scene.

## History / decisions worth knowing

- **Two-ball design was a user constraint** — "make him just two balls,
  make the head good at least ... try to be simple to make less fuck ups."
  Adding limbs / a full rig is a scope expansion the user hasn't approved.
- **Uncanny-valley fix:** an earlier version had the face patch buried inside
  the head sphere so only a paper-thin sliver protruded; the eyes appeared to
  float on bare cream and read as creepy. Fix was pushing the patch flush to
  the front of the head (`y = -HEAD_R * 0.88`, `y-scale = 0.40`) so it reads
  as a distinct mask. Don't undo this.
- **Cuteness overshoot:** a followup added tall bat ears, eye sparkles, blush
  cheeks, a smile, and feet. User rejected it ("no undo undo WHAT HAVE YOU
  DONE") and we reverted. Current model is the sober version; don't reintroduce
  those features unless the user asks.
- **Colors came from the emoji, not chosen from taste.** Palette is fixed
  unless the user overrides.
- **Vertex-color → PBR-material switch** happened when the user asked for
  named material slots so the game could retint per role. The older
  vertex-color-only export (visible in git history if there is one) still
  works as a viewer but has no slot names.

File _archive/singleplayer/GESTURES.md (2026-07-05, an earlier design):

# GESTURES.md — what the games need from the wristband

Two kinds of input the games can consume:

- **Trained multi-class gestures** — the `Classifier` in `app/classifier.js`
  emits discrete gesture events with labels like `jab`, `hook`, etc. Requires
  labeled reps from `tools/collect.py` and threshold tuning against
  `tools/replay.mjs`.
- **Raw per-sample stream** — the game reads every IMU sample and does its own
  detection. No training data required; tune constants in the game's own file.

Different games use different amounts of each.

---

## Boxing (`boxing.html`)

**Trained gestures — need labeled data.** Currently the classifier is in
JAB-ONLY mode (see JOURNEY.md for why). Restore the discriminator once fresh
reps land for each label below.

| Label | Description | Signature |
|---|---|---|
| `jab` | Sharp straight forward punch from guard, snap back. | Big `+X` accel, low rotation. |
| `hook` | Horizontal hooking punch, elbow ~90°, arc across body. | Big `gy` (yaw) or `gx` (forearm roll), moderate accel. |
| `uppercut` | Upward punch from hip level, drive up. | Big `+Y` accel, pitch snap. |
| `block` (hold) | Forearm up in front of face, palm inward, hold ≥ 0.5s still. | Sustained low motion + specific orientation. |
| `idle` (hold) | Baseline noise floor — arm relaxed, don't move. | Sets rest thresholds. |
| `dodge_left` | Lean torso left, band travels with it. | Lateral accel + held roll. |
| `dodge_right` | Lean torso right. | Same, opposite sign. |
| `dodge_back` | Lean body backward, pull head away. | Backward accel, brief. |

**Priority: `jab`, `hook`, `uppercut`, `block`, `idle` first — enough for a
playable demo. Dodges are polish.**

Collect with:
```bash
cd day3/tools
python collect.py --arm 0     # right arm
python collect.py --arm 1     # left arm
node replay.mjs               # verify accuracy per label
```

---

## Bowling (`bowling.html`)

**Raw-detected — no training data needed.**

Single gesture: **`bowl_swing`**.

- Physical motion: underhand arm arc (like a real bowling delivery). Arm
  starts up/behind, swings forward and down through the release point.
- Detection: watch peak `|gyro|` over a rolling window. When gyro drops
  back below ~30% of the peak, that's the release moment. Ball launches:
  - **Speed** = `peak_gyro / GYRO_MAX` (clamped 0..1)
  - **Angle** = wrist roll or `ax` at release moment (aims left/right)
- Tuning knobs live at the top of `bowling.html`.

If the raw detector gives false positives (e.g. from any wave), fall back to
gating on a rough swing envelope: peak `|gyro| > 300 dps` **and** peak
`horizontal accel > 8 m/s²` inside the same 500ms window.

---

## Tennis (`tennis.html`)

**Raw-detected — no training data needed. Timing-critical.**

Gestures:

- **`tennis_swing_forehand`** — right-arm horizontal swing, ball in front of
  body. Similar to a hook but wider arc + you're expecting the ball at a
  specific moment.
- **`tennis_swing_backhand`** — right-arm horizontal swing crossing the body
  (right-to-left for a right-hander). Detect by sign of the yaw rate.

Detection: watch for a big rotational + translational spike (peak `|gyro|`
above ~250 dps, peak accel above ~10 m/s²) inside the "ball is hittable"
window scripted by the game.

If the swing lands inside the hittable window → return the ball. Outside → miss.

- **Return direction** = wrist tilt (roll) at moment of peak.
- **Return power** = peak accel magnitude.

Forehand vs. backhand: sign of yaw rate (`gz` or gravity-aligned `w_yaw`).
Positive = forehand (right → left across body for a right-hander),
negative = backhand.

---

## Baseball (`baseball.html`)

**Raw-detected — no training data needed. Timing-critical.**

Single gesture: **`bat_swing`**.

- Physical motion: horizontal swing, both arms out to one side (right-handed
  batter: right-shoulder-back to left-shoulder-forward). Wristband is on the
  lead arm (whichever the batter's forearm the sensor is on).
- Detection: large peak `|gyro|` (>350 dps) **inside** the "ball is in strike
  zone" window (~200ms during pitch travel).
- Contact if peak lands in window → ball flies out. Miss otherwise.

Distance / trajectory:
- **Exit velocity** = peak accel magnitude → clamps to a HOME_RUN threshold.
- **Launch angle** = wrist pitch at moment of peak. Above horizontal → fly
  ball. Below → grounder.
- **Pull vs. opposite field** = wrist yaw / horizontal swing plane.

---

## Summary: what training team needs to collect

**Highest priority (boxing demo dependencies):**

1. `jab` — 20 reps per arm
2. `hook` — 20 reps per arm
3. `uppercut` — 20 reps per arm
4. `block` — 20 reps per arm (hold mode)
5. `idle` — 20 reps per arm (hold mode)

**Nice-to-have** (only if `hook`/`uppercut` don't discriminate reliably from `jab` with the current features):

- Include a "wrist twist only" negative class (`idle_twist`) so the trained
  classifier learns to reject pure wrist rotation. Do 20 reps: just twist
  the forearm palm-up-to-palm-down without translating the hand.

**Not required for launch** — bowling / tennis / baseball detectors are all
raw-sample based. Tune the constants at the top of each game's HTML file
against how the swing feels, no training pass needed. If any of them start
firing accidentally on other gestures, we add a per-game gate later.

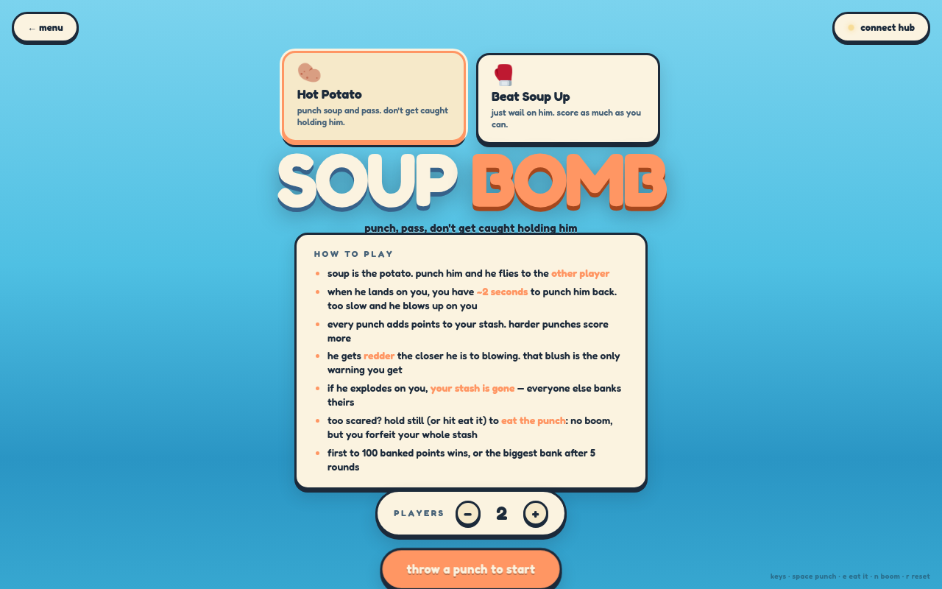
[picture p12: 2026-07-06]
docs/img/screenshots/punch-bomb.png

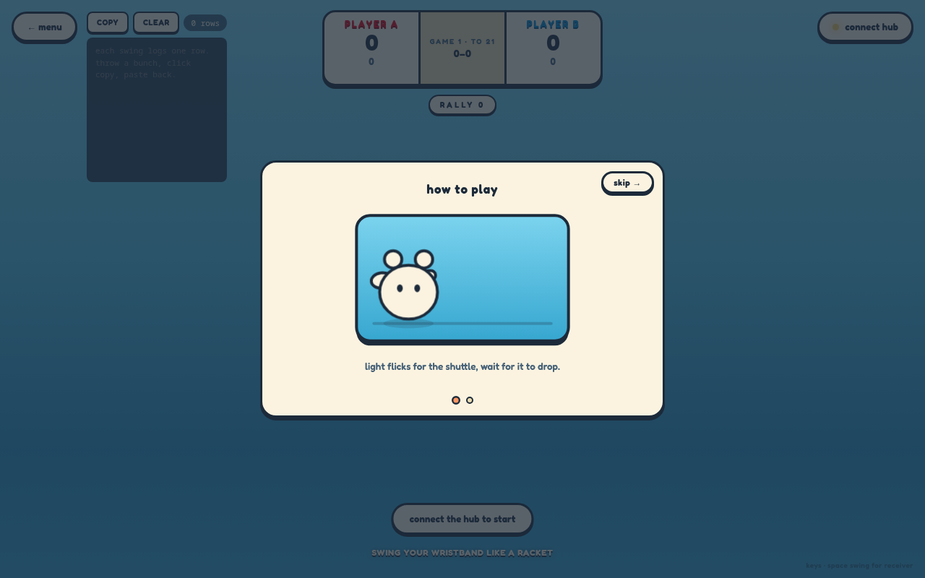
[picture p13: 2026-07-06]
docs/img/screenshots/badminton.png

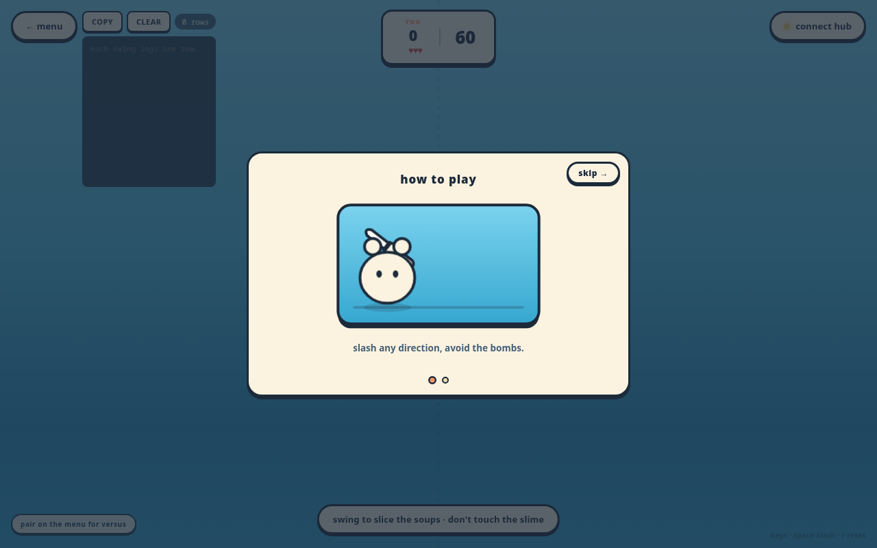
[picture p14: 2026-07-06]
docs/img/screenshots/fruit-ninja.png

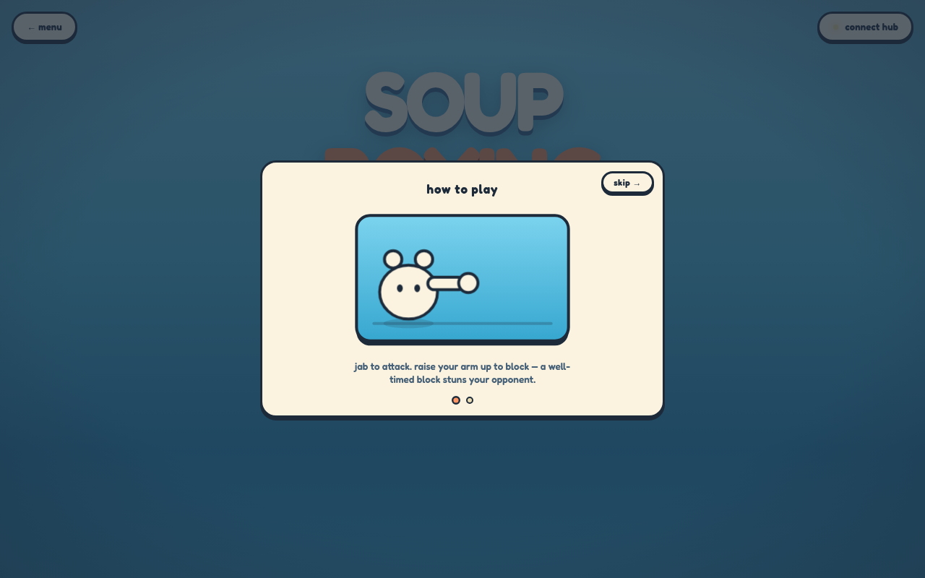
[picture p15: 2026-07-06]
docs/img/screenshots/boxing.png

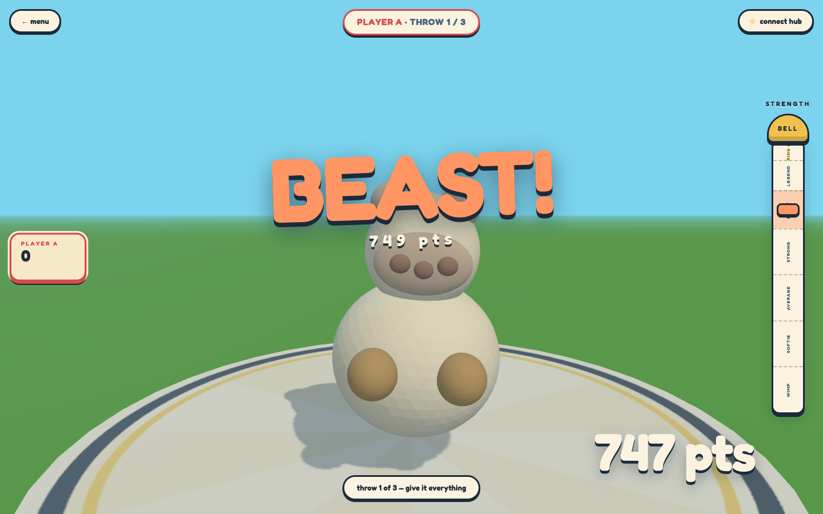
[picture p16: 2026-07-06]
docs/img/screenshots/slugger-play.png

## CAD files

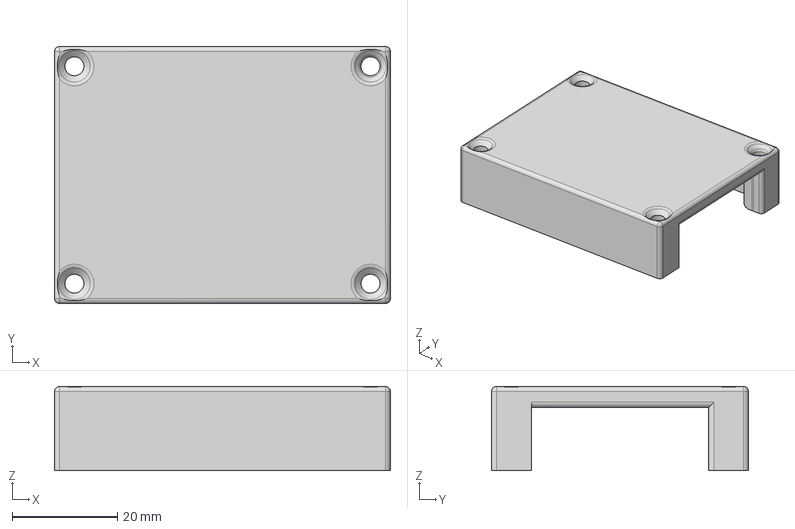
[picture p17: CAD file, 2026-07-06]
3D models/Top Watch Top.step
64.0 x 49.0 x 16.0 mm

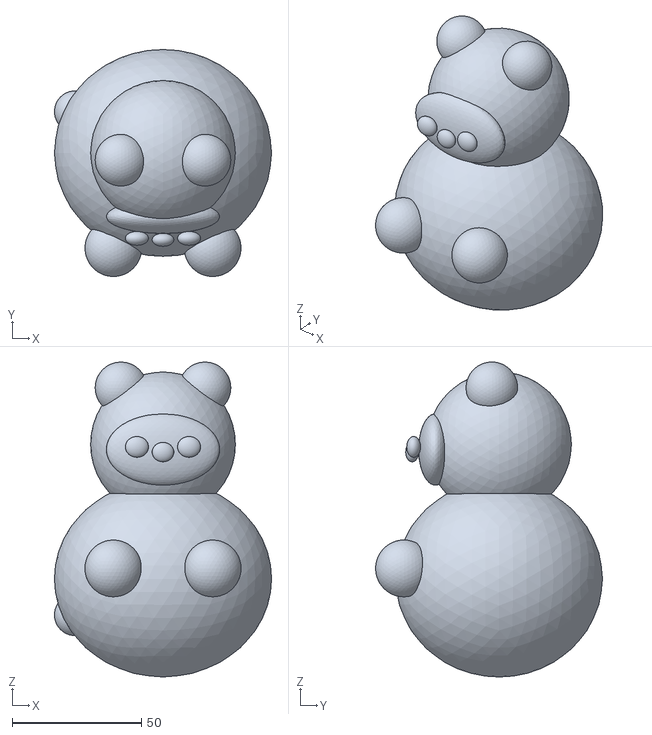
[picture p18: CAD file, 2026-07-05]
soup/soup.stl
84.0 x 87.8 x 121.8

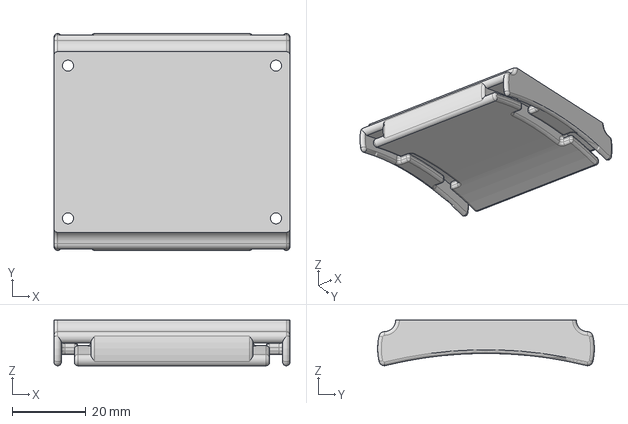
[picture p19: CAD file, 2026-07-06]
3D models/Top Watch Base.step
64.0 x 58.8 x 12.4 mm

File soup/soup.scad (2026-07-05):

// soup — a chubby lil guy
// two-ball design: big body sphere + head sphere on top
// units: mm. print at whatever scale you like.

$fn = 80;  // sphere smoothness

// --- tunables ---
body_r   = 40;      // body radius
head_r   = 28;      // head radius (a bit smaller so head sits on top)
head_dz  = 52;      // head center height above body center
ear_r    = 9;       // ear radius
eye_r    = 3.2;     // eye radius
nose_r   = 4.0;     // nose (the middle dark blob)
arm_r    = 10;      // little paw radius
tail_r   = 8;       // tail radius

// --- body (bottom ball) ---
// squish slightly so he sits flat and looks chonky
module body() {
    scale([1.05, 1.0, 0.95])
        sphere(r = body_r);
}

// --- head (top ball) ---
module head() {
    translate([0, 0, head_dz])
        sphere(r = head_r);
}

// --- ears: two little bumps on top of head ---
module ears() {
    for (sx = [-1, 1]) {
        translate([sx * (head_r * 0.55), -head_r * 0.15, head_dz + head_r * 0.75])
            sphere(r = ear_r);
    }
}

// --- face patch: flatter oval on front of head (the darker mask area) ---
// modeled as a very shallow disc pushed into the head front
module face_patch() {
    translate([0, -head_r * 0.85, head_dz - 2])
        scale([1.2, 0.3, 1.0])
            sphere(r = head_r * 0.55);
}

// --- eyes + nose: three little bumps on the face ---
module face_details() {
    // eyes
    for (sx = [-1, 1]) {
        translate([sx * (head_r * 0.35), -head_r * 0.95, head_dz + 2])
            sphere(r = eye_r);
    }
    // nose (center, slightly lower)
    translate([0, -head_r * 0.98, head_dz - 3])
        sphere(r = nose_r);
}

// --- arms: two small paws on the front of the body ---
module arms() {
    for (sx = [-1, 1]) {
        translate([sx * (body_r * 0.55), -body_r * 0.55, body_r * 0.05])
            sphere(r = arm_r);
    }
}

// --- tail: little nub off the back-left ---
module tail() {
    translate([-body_r * 0.85, body_r * 0.4, -body_r * 0.35])
        sphere(r = tail_r);
}

// --- assemble ---
module soup() {
    union() {
        body();
        head();
        ears();
        face_patch();
        face_details();
        arms();
        tail();
    }
}

soup();

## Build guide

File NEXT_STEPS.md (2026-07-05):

# NEXT_STEPS.md — pick up here

**Read `CLAUDE.md` first for permanent orientation.** This file is the "what
was just decided and what's in flight" companion — everything the previous
session ran through that isn't obvious from the code alone.

Last update: post-menu-redesign, ~1 hr after commit `d60d7c1`.

---

## Where the project is right now (60-second summary)

**Soup Sports** — a wireless-wristband arcade with 5 playable Wii-Sports-style
minigames. The repo has been through significant pivots (SpaceEngine →
Wii-Sports → Soup Sports rebrand — see `JOURNEY.md`). The direction is
**locked**. Do not re-propose SpaceEngine, gesture-driven flight, or
cockpit/joystick variants.

### What's built + shipped to `main`

- **5 games all playable and polished** at `day3/app/`:
  1. `boxing.html` — jab/hook/uppercut vs Soup opponent, first-person gloves, KO celebration with 90-piece confetti
  2. `bowling.html` — 10 tiny Soups as pins with hue jitter, chain-reaction knockdown, real 10-frame scoring, strike/spare/gutter banners
  3. `tennis.html` — swing timing vs CPU Soup across the net, rally streak with flame emoji, first to 5 rallies
  4. `baseball.html` — home-run derby vs pitcher Soup, HR distance callouts, incoming ball trail
  5. `punch_bomb.html` — **the party game.** Push-your-luck, punch Soup, hold-still-to-bank, hidden bomb count. 2-4 players.
- **Menu at `index.html`** — hand-drawn cozy meadow backdrop (tree stumps,
  wildflowers, birds), 5 cards, live 3D Soup mascot with wave.
- **Wireless firmware** in `day3/firmware/`: three PIO envs
  (`wrist_right`, `wrist_left`, `dongle`) sharing one `src/`. Broadcasts on
  ESP-NOW channel 1. Wire format is `arm,t_us,ax,ay,az,gx,gy,gz,roll,pitch`.
- **Training pipeline** in `day3/tools/`: auto-trigger `collect.py` +
  `replay.mjs` regression harness. Consumes both day1 and day3 wire formats.
- **Docs**: `CLAUDE.md`, `JOURNEY.md`, `day3/GESTURES.md`,
  `soup/HANDOFF.md`, this file.
- **Repo hygiene**: `.pio/` and `managed_components/` gitignored. 
  Pushed to `git@github.com:GuyOnWifi/fallout.git`, branch `main`.

### What's live on localhost right now

`python -m http.server 8123` is running from `day3/app/`. All 5 games plus
menu are accessible at http://localhost:8123.

---

## In-flight work + open questions

### 1. Two-player modes (asked, not yet built)

**The user just asked whether 2P should be one-hand-per-player or
two-hands-per-player.** My recommendation (agreed by the direction of the
conversation but not confirmed):

- **Solo (1 wristband) — default for bowling/tennis/baseball/bomb.** One
  hand controls everything.
- **Solo (2 wristbands) — default for boxing only.** Dual-wield gloves.
  Most iconic Wii Sports feel.
- **VS (2 wristbands, one per player)** — 1v1 mode for boxing, bowling,
  tennis, baseball. Arm 0 → P1, arm 1 → P2. `ArmDispatcher` already routes
  per-arm; just add a per-player game state.

**To build:** each game needs a mode toggle in a small pre-game screen
(or on the menu card). Modest per-game work; recommend spinning up 3-4
parallel agents when the user greenlights.

### 2. Classifier is in JAB-ONLY mode

`day3/app/classifier.js` was tuned on day1 data with a specific arm mount.
When the wireless firmware moved the sensor, thresholds drifted. Instead of
retuning without fresh data, `_classify()` was short-circuited so any valid
trigger fires `jab`.

- **Bowling/tennis/baseball/punch_bomb DO NOT USE the classifier** — they
  consume raw samples via a `dispatcher.onLine` monkey-patch (pattern from
  `bowling.html`). Not affected.
- **Boxing needs the multi-class classifier restored** to discriminate
  jab/hook/uppercut. Blocked on training data.

**Buddy is doing training** — see `day3/GESTURES.md` for the priority list
(jab, hook, uppercut, block, idle × ~20 reps per arm minimum). When those
CSVs land in `day3/tools/data/`, restore the multi-class branch in
`_classify()` and run `node replay.mjs` to verify.

### 3. Menu overflow (just fixed, worth re-verifying)

The user reported the home page overflowed without scroll. Just addressed
in commit `d60d7c1` — tighter padding, smaller hero, smaller cards. **Take
a fresh screenshot to confirm it fits at 1280×800 and typical phone
viewports.**

### 4. Hardware side is still untouched

All demo polish so far has been web. The physical build (cardboard
cabinet with phone mount, wristband strap + LiPo + vibration motor, 3D
print jobs) is the biggest remaining risk. Software floor is ready.
Hardware floor is not.

---

## Design language quick-reference (Soup Sports)

**Palette (locked):**
```
--sky-top     #d3ecf7    --grass-lite  #c5e0a6    --wood-lite   #b98b6a
--sky-mid     #b6dff2    --grass       #a8ce85    --wood        #8f5f42
--sky-deep    #94cfe8    --grass-deep  #7fb060    --wood-deep   #5f3d28
--cream       #fbf3e0    --grass-tuft  #5a8f4a    --wood-ring   #6f4630
--cream-warm  #f6e9c9    --vine        #6cb85a    --ink         #2b1e14
--cream-deep  #ecdcb1    --vine-deep   #4a9440    --ink-soft    #5a4a3d
--hot         #ee7b52    --gold        #f2c14d    --petal-pink  #f7b8c4
```
(Older `--ruin-*` and `--water` tokens still exist for legacy HUD refs.)

**Look:**
- Cream HUD panels with 3px ink borders + hard `0 4px 0 var(--ink)` drop shadows.
- Chunky rounded typography (Fredoka / Nunito / SF Pro Rounded).
- `.ss-btn` treatment: cream pill, ink border, hard drop shadow, hover-lift.
- Status pill: cream bg, gold pulse dot when disconnected → vine-green when connected.

**Menu backdrop specifically:**
- Hand-drawn meadow: sky-cyan-to-grass gradient, wobble-filter-jittered hill silhouettes, chunky tree stumps with wood rings + ivy, wildflower + mushroom accents, two bird silhouettes.
- NO grid-perfect rectangles, no gradient-heavy buildings, no crosswalks
  — those read as AI-generated.

---

## Mascot (Soup)

- File: `day3/app/assets/mascot.glb` (mirrored from `soup/soup.glb`).
- Node names: `body, ears, face_patch, eyes_nose, paws, tail`.
- Load: `soup.rotation.x = -Math.PI/2; soup.scale.setScalar(0.008)` for ~1m.
- **Do not add a second `soup.rotation.y = Math.PI`** — this bug hid the
  tennis CPU due to backface culling. See tennis polish agent report.
- Materials must be cloned before per-instance tinting.
- **No rig, no animation clips.** All animations are procedural (idle bob,
  hit shake, KO tween, bowling_pin_fall). Recipes in `soup/HANDOFF.md`.
- **Do NOT add facial detail, sparkles, ears, feet, blush, smile** — prior
  session overshot cuteness and got "no undo undo WHAT HAVE YOU DONE"'d.

---

## Puppeteer verification pattern (works reliably)

```bash
# Playwright chromium is at /home/guyonwifi/.cache/ms-playwright/chromium-1228/chrome-linux64/chrome
# playwright-core installed at /tmp/ss-node/node_modules/playwright-core
# The script:
cat > /tmp/ss-screens/shoot.mjs <<'EOF'
import pkg from '/tmp/ss-node/node_modules/playwright-core/index.js';
const { chromium } = pkg;
const pages = ['index','boxing','bowling','tennis','baseball','punch_bomb'];
const browser = await chromium.launch({
  executablePath: '/home/guyonwifi/.cache/ms-playwright/chromium-1228/chrome-linux64/chrome',
  headless: true,
});
const ctx = await browser.newContext({ viewport: { width: 1280, height: 800 } });
for (const p of pages) {
  const page = await ctx.newPage();
  await page.goto(`http://localhost:8123/${p === 'index' ? '' : p + '.html'}`,
                  { waitUntil: 'networkidle', timeout: 10000 });
  await page.waitForTimeout(2500);   // GLB load buffer
  await page.screenshot({ path: `/tmp/ss-screens/${p}.png` });
  await page.close();
}
await browser.close();
EOF
node /tmp/ss-screens/shoot.mjs
```

Screenshots at `/tmp/ss-screens/*.png`. Historical
`day3/_screens_before/`, `day3/_screens_after/` folders track visual
progress across commits.

---

## Recent commit history (reverse chronological, last 6)

```
d60d7c1  Menu: hand-drawn meadow backdrop + compact layout
e17d948  5th game + tennis + boxing polish + fresh screenshot pass
014e505  Painterly ruin backdrop + polish landings + Soup Bomb slot
9642deb  Real 3D Soup on the landing page
005c128  Soup Sports — four-game arcade with mascot integration
552acc8  day3 wireless boxing prototype + CLAUDE.md orientation
```

---

## Rules of engagement for the next session

Repeat of `CLAUDE.md`'s "What NOT to do" section, with extras:

- Do NOT re-propose SpaceEngine, gesture-flight, cockpit, joystick, or
  "explore the universe" variants. See `JOURNEY.md` for the full graveyard.
- Do NOT add facial detail, sparkles, ears, feet, blush, smile, or eye
  highlights to the Soup mascot unless the user explicitly asks.
- Do NOT rewrite the classifier from scratch — real thresholds tuned to
  real data.
- Do NOT touch `day1/` — historical snapshot.
- Do NOT push to `main` without asking (this session pushed a lot, but each
  push was explicitly requested — read the request pattern).
- **Do use parallel general-purpose agents for polish work at file-level
  scope.** Both major sprints in this session used them successfully
  (4 games polished in ~15 min wall-clock).
- **Do use puppeteer to verify UI/UX before claiming success** — the earlier
  session claimed things worked visually without checking and got called
  out. The screenshot pattern above is proven working.

---

## Immediate priority queue (best-guess for next session)

1. **Verify menu overflow is fixed** (fresh screenshot at 1280×800).
2. **Answer the 2P mode question and spin up agents to implement** if the
   user confirms.
3. **Restore multi-class classifier** once training data arrives (buddy's
   working on it).
4. **Hardware CAD + cabinet build** — biggest lurking risk. Not software.
5. **Optional audio pass** — one whoosh + one hit + one crowd loop per game.
   30 min each, doubles perceived polish.

## Files a new session should read in this order

1. **`CLAUDE.md`** — evergreen orientation, palette, mascot, rules.
2. **`NEXT_STEPS.md`** (this file) — recent activity, in-flight.
3. **`DEVLOG.md`** — technical war stories, presentation-ready. **Append new
   bug-fix stories at the top** as they happen. Format: "Symptom → Debug →
   Fix → Lesson." Doubles as demo-day talk material.
4. **`JOURNEY.md`** — pivot history so mistakes don't repeat.
5. **`day3/GESTURES.md`** — what each game consumes from the wristband.
6. **`soup/HANDOFF.md`** — mascot 3D details.

That's ~1700 lines total. Reasonable startup cost for a fresh session.

## Docs discipline for this repo

- `CLAUDE.md` — **evergreen.** Rewrite in place; older sections should stay
  true forever.
- `NEXT_STEPS.md` — **rolling.** Update as work state shifts. Don't append,
  rewrite in place.
- `DEVLOG.md` — **append-only, newest-first.** Every new bug fixed = new §
  at the top. Every clever solution = story worth writing down. This is
  where the demo-day talk lives.
- `JOURNEY.md` — **append-only.** Records completed pivots and their
  rationales. Don't edit prior entries.
- `day3/GESTURES.md` — **spec.** Update when adding new games / gestures.
- `soup/HANDOFF.md` — **spec.** Update when the mascot model changes.

Any session that fixes a real bug **should add a new § at the top of
DEVLOG.md** with the Symptom/Debug/Fix/Lesson format. Users have explicitly
asked for this pattern to be maintained.

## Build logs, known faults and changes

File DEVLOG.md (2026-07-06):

# DEVLOG.md — technical war stories from the Soup Sports build

Running devlog of bugs hit, root causes found, dead ends, and clever fixes.
Written to double as a technical presentation for the hackathon demo — each
entry stands alone as a 30-second story you could tell on stage.

**Format:** every entry has *The Symptom*, *The Debug*, *The Fix*,
*The Lesson*. Append new entries at the top so the timeline reads
newest-first when scrolling.

---

## §16. The block gesture and the phantom Soup Bomb turn skip

**The symptom.** Soup Bomb sometimes ended a player's turn immediately —
one small motion after the "you're up" banner and the game would jump
straight to the next player. It felt like the classifier was making up
punches.

**The debug.** Added a per-event log in punch_bomb.html and confirmed
`punchesThisTurn` was jumping to 3+ within milliseconds of the round
starting. Correlated with wristband dynA — the phantom punches happened
during arm *raise*, not arm *thrust*. That's the shape of a block.

**The fix.** Two lines in punch_bomb.html — `if (g.gesture !== 'jab') return;`
in the dispatcher's classifier-event handler. Blocks now silently no-op
in Soup Bomb (it doesn't have a defensive gesture concept). Punches count
as before.

**The lesson.** When a shared module (classifier) grows new event types,
every downstream consumer has to be audited. A block was a *gesture*
and the dispatcher forwarded it dutifully; punch_bomb assumed all
gesture events meant "punch." The right fix wasn't in the classifier
(where blocks are legitimate) but in the consumer that couldn't
distinguish them.

---

## §15. Simplifying the boxing classifier to jab + block

**The symptom.** Live-tuning the 3-way jab/hook/uppercut classifier kept
hitting the same wall — the user's live motion produced feature clusters
that overlapped between hook and uppercut. A wrist rotation during a
"hook" made features look uppercut-shaped; an upward drive on an
"uppercut" made features look like a jab. Sample logs showed 50–70%
accuracy under 3-way discrimination and no single feature axis that
could reliably split them.

**The debug.** Three separate live-tuning sessions collected batches
of jab/hook/uppercut with the ask "these were all X" and each time the
features overlapped enough that any rule tuned for one batch broke the
others. The gravity-aligned features assume rotation-invariance to first
order, but during a swing the wrist rotates 30–90° — Mahony-style
attitude fusion would fix it, but that's not a demo-day project.

**The fix.** Collapse to two gestures: `jab` (any peak-detected swing
that doesn't look like a guard) and `block` (any peak-detected swing
with big `up` peak and near-zero `down` peak — an upward guard motion).
`up ≥ 22 AND down ≤ 15 → block`, else → jab. Boxing repurposes hook
and uppercut animations as visual variety on jabs; damage tables kept
for legacy dev shortcuts. The refractory dropped from 850 ms → 450 ms
so back-to-back jabs stop getting swallowed.

**The lesson.** Sometimes the fix is to remove a class, not to tune
a threshold. The 3-way problem was fundamentally under-observed —
we only had translational accel and gyro, and the three punches share
a lot of the same signal. Two classes with genuinely different feature
signatures (attack vs. guard) is a completely different problem than
three attacks with overlapping signatures. Trade: lost animation
richness on the input side, gained reliability that survives a demo.

---

## §14. Tennis: ballistic net-clearance iterator and the let-cord bounce

**The symptom.** Every rally return in tennis hit the net. The serve
worked because the ball starts at ~2.3 m (above the mascot's head), so
the ballistic arc naturally cleared the 0.914 m net. Returns started
from `ball.position` — which was ~3 cm off the ground after a bounce —
and the ballistic solver's `minT = 0.55 s` gave a low, fast arc that
peaked at ~0.4 m. The net top is at 0.914 m. Every return smacked
straight into it.

**The debug.** Symbolically computed the ball's y-height at the z=0
crossing: `y_net = from.y + vy·t_net − 0.5·g·t_net²`, where
`t_net = |from.z| / |vz|`. Plugged in the actual numbers and got 0.4 m.
Net is 0.914. Zero clearance, always.

**The fix.** Two-part.

1. **Iterate the arc.** `ballisticVelocity` now checks the linear-interp
   height at z=0 crossing and, if it's under `NET_H_CENTER + 0.35`,
   stretches `t` by 18% and recomputes. Up to 6 iterations, capped at
   `maxT = 1.6 s`. Returns naturally get taller arcs when they need
   them; serves that already clear the net don't waste time.
2. **Net-cord bounce instead of point-loss.** Even with the iterator,
   the ball can theoretically still clip the top of the net (rare
   edge case). Instead of ending the point, the ball now deflects off
   the net cord back to the hitter — `vy → |vy|·0.6 + 1.2` upward,
   `vx → 0.6·vx`, `vz → −0.35·vz`. Play continues. Real tennis calls
   this a "let cord;" here it's a demo-day fairness knob.

Trade-offs, honestly: the iterator makes returns look a bit floaty
compared to real tennis (max arc time bumped from 1.2 s → 1.6 s), but
the alternative was a game that felt unwinnable.

**The lesson.** Physics simulation constants that work for one initial
condition (serve from high) can silently fail for another (return from
low) even when the code is identical. When you add a new call site to
a shared solver, walk the physics in both regimes on paper before
trusting it.

---

## §13. Universal wristband firmware — MAC-derived arm_id

**The symptom.** With two wristbands live at the same time, the browser's
pairing menu would only ever fill slot A. Slot B stayed empty. The user
also had to remember which env to flash (`wrist_a` vs `wrist_b`), and any
mismatched flash silently produced a "phantom" arm ID that no browser
game would route correctly.

**The debug.** Two compounding problems.
1. ARM_ID was a compile-time constant (`-DARM_ID=0/1`) baked in per env.
   Flash the wrong env and you got two wristbands claiming arm 0. The
   dongle happily forwards both streams — they interleave into arm 0's
   classifier state machine and neither works.
2. Even after fixing #1, sessionStorage in pairing.js had a stale
   `{ A: 0, B: 1 }` from the old two-arm world. New MAC-derived arm_ids
   (5-digit ints like 33221) never matched, so slot A appeared "already
   assigned" and the first shake fell through to slot B, leaving the
   second wristband with nowhere to go.

**The fix.** Two moves.
1. In `wrist.cpp`, replace the `#define ARM_ID` with a runtime derivation:
   `esp_read_mac(mac, ESP_MAC_WIFI_STA); arm_id = (mac[4]<<8) | mac[5];`
   The last 2 bytes of the WiFi MAC are chip-unique (collisions at ~1 in
   65k, comfortably below hackathon demo scale). One binary flashes any
   wristband. Deleted the `wrist_a` / `wrist_b` envs from platformio.ini.
2. In `pairing.js`, bump `STORE_KEY` from `v1` to `v2`. Old cached
   assignments get invalidated the moment the page loads.

Nothing on the browser side needed changes — `dispatch.js` and
`pairing.js` already keyed on `armId` as an opaque integer, so the
transition from 0/1 to 5-digit MAC ints was zero-refactor.

**The lesson.** Compile-time device identity is a foot-gun for
multi-device setups. Chip-unique identity (MAC, efuse) is free on ESP32
and eliminates a whole class of "did I flash the right env" bugs. Persist
state with a version key so schema changes don't strand users on stale
caches.

---

## §12. The §11 bug was hiding in three more files — full-UI design audit findings

**The symptom.** A design audit pass over all six pages started from
screenshots and immediately found three missing mascots that nobody had
reported: the landing-page hero Soup (menu), the bowler Soup (bowling), and
the pitcher Soup (baseball) all rendered zero pixels. Each page logged
"mascot loaded" happily. On top of that, the UI itself read as
machine-generated: every game had invented its own button styles and corner
positions, two games drew raw debug logs on screen ("[12:52:25] mascot
loaded"), bowling and tennis showed two competing instruction banners at
once, and the copy was full of ALL-CAPS imperatives, em dashes, and
exclamation points.

**The debug.** All three invisible mascots shared the same line:
`soup.rotation.y = Math.PI` after the canonical `rotation.x = -Math.PI/2`
flip — the exact bug documented in §11 for tennis. Setting both angles on
one Euler does not compose the way the comment claims ("face -Z"): with
three.js's default XYZ order the pair lands the mascot upside down /
inverted, so he ends up below the floor or showing no lit pixels. §11
documented the fix but only fixed tennis; the same copy-pasted line
survived in index.html, bowling.html, and baseball.html. Notably the
baseball comment even said "face -Z (toward home plate)" — but home plate
is in +Z from the mound, so the flip was wrong twice.

**The fix.** Delete the y-flip in all three files (after the x-flip the
mascot already faces +Z, which is toward the camera/plate in every one of
these scenes). The menu hero, bowling sideline Soup, and pitcher all render
now. The rest of the audit unified the chrome across all six pages: one
`.ss-btn` pill treatment, menu pill top-left, a single hub pill top-right
that doubles as the connect button *and* the status indicator (the separate
status pill is gone — one element fewer per page, and the connect button no
longer disappears when dev keys fire `game-active`), score HUD top-center
(dropping to `top: 64px` under 640px so nothing collides on the phone),
prompts as lowercase cream pills bottom-center, dev-key hints as faint
bottom-right text hidden on phones, debug `#log` display:none. Copy
rewritten throughout (no em dashes, no exclamation-point design, lowercase
voice; "Punch Bomb" renamed to its real name Soup Bomb). Emoji-as-icons
(🥊🎾💨🔥 etc.) replaced with small inline SVGs. Boxing and Soup Bomb got
aspect-aware FOV (55° landscape → ~70° portrait) so Soup doesn't swallow
the phone frame in the cardboard shroud.

**The lesson.** When a bug is documented as fixed, grep for the offending
line across the whole repo before closing it — §11's line was copy-pasted
into four files and only one got fixed. `grep -rn "rotation.y = Math.PI"
day3/app/` would have caught all of them in one shot months of demo-time
earlier. And for UI: screenshots at both 1280×800 *and* 390×844 are the
audit tool — every mobile overlap found in this pass was invisible at
desktop size.

---

## §11. "The CPU was there but invisible" — tennis mascot backface bug

**The symptom.** After the tennis polish pass integrated the Soup mascot as
the CPU opponent, the placeholder sphere rendered fine but the loaded GLB
rendered as literally zero pixels. Verified in Puppeteer screenshots: net
visible, court visible, no soup across the net. Console showed the model
loaded successfully. Placeholder swap logic ran. Where was he?

**The debug.** The obvious "he's off-camera" hypothesis was checked first —
scaled to 5m tall to overwhelm any framing issue. Still nothing on screen.
Bounding-box print from Three.js showed the mesh existed at
`(0, 0..2.4, ~far-baseline)` — well within camera view. That ruled out
transform, scale, and position.

Attention turned to material state. Rendering with `MeshBasicMaterial` red
override worked — every polygon on screen. Rendering with the loaded PBR
material didn't. **The problem was in the transform chain, not the material.**

Look at the load code:
```js
soup.rotation.x = -Math.PI / 2;   // z-up model → y-up scene
soup.rotation.y = Math.PI;        // "face -Z toward the player"
```

Two rotations in Euler XYZ compose. The first flip is canonical (from
`soup/HANDOFF.md`). The second rotation was added "to face the player" —
but after the -π/2 X-flip, the mascot's face is already pointing +Z toward
the camera. The extra Y-flip rotated the world such that **all polygons
were oriented away from the camera**. Three.js's default backface culling
skipped every triangle. Present but invisible.

**The fix.** Delete the `soup.rotation.y = Math.PI` line. Trust the HANDOFF
doc.

**The lesson.** Two rotations that "should" compose intuitively actually
combine into something that inverts winding order. When a mesh loads,
renders, has correct transform state, but shows no pixels — think about
face orientation before you think about anything else. Also: when a HANDOFF
doc says "after the flip, the face already points +Z," believe it.

---

## §10. Bowling camera framing: pins as horizon dust

**The symptom.** First bowling screenshot: pins were 2-pixel specks at the
top of the frame, ball was invisible, tutorial overlays visible but the
actual game was unreadable. Judge would look at this and go "where's the
game?"

**The debug.** Three separate camera-vs-scene bugs stacked:

1. Camera at `(0, 1.7, 2.5)`, ball at `z = 1` — ball is *behind* the camera
   at z=2.5 looking down the -z axis to the pins.
2. Pins at `z = -25`, camera at 55° FOV. At that distance a pin is
   ~0.35m tall, subtending under 1° of the frame.
3. Fog `(8, 30)` hazed the pins even more.

Three bugs, one visible outcome ("nothing to see").

**The fix.** Reframe: camera → `(0, 2.2, 4.5)`, look at `(0, 1.0, -6)`. Pins
moved to `z = -9`. Pin scale 0.0025 → 0.0075 (3x). Backstop wall added
behind the pins so they read against a solid surface, not sky. Fog pushed
to `(16, 45)`. Now pins fill ~15% of the frame — legible and inviting.

**The lesson.** "Nothing on screen" almost always means multiple small
things combining. Debug one axis at a time: put a giant red sphere at
`z = 0` to prove camera framing; then add scale; then add fog. Camera bugs
compound with scale bugs and both compound with fog. Isolate.

---

## §9. Four polish agents in parallel finished faster than one would

**The situation.** Needed four games (boxing, bowling, tennis, baseball)
each polished to the Soup Sports brand. Sequentially: ~2 hours. In parallel
with clean file-level scope: **~15 minutes wall-clock, all four**.

**The recipe that worked.** Each agent got:
- A **before-screenshot** in the prompt so they could see the current state.
- A **single-file write scope** (`bowling.html` only, etc.) — no shared
  state to merge, no diffs to reconcile.
- **Explicit "do not touch" list** naming the shared JS modules and other
  games so nobody stomped on parallel work.
- A **detailed spec** with pixel-level palette + specific animation recipes.
- A **verification handle** (curl + Puppeteer screenshot path) so they
  could self-verify before returning.

**The failure mode that could have happened.** If two agents had needed to
touch `dispatch.js` or `classifier.js`, the last one to write would clobber
the first. Would have wasted an agent-hour. Avoided by carefully scoping.

**The lesson.** Parallel agents work when: (1) file-level ownership is
clean, (2) each has a self-verification path, (3) each has a "don't touch"
list explicitly naming the shared code. The 15-minute run cost per game
compounds into massive wins if you have real parallelism.

---

## §8. The MPU6050 that wasn't (WHO_AM_I = 0x70)

**The symptom.** Wired up a GY-521 "MPU6050" board. Adafruit's `mpu.begin()`
returned false. I²C bus scan said something was answering at address `0x68`.
The chip existed. Adafruit refused to talk to it.

**The debug.** Read the WHO_AM_I register directly (`0x75`). Expected
`0x68`. Got **`0x70`**. That's the identifier for an **MPU6500** — the
successor chip. The board silkscreen said "MPU6050" but the actual silicon
was different. Adafruit's library strictly checks WHO_AM_I and refuses
anything that doesn't match.

**The fix.** Ditched the library. Wrote a hand-rolled I²C driver
(`day3/firmware/src/mpu.h`, ~40 lines) that just knows the shared register
map. MPU6050 and MPU6500 use identical registers for basic accel + gyro —
different WHO_AM_I values, same functionality. Works with either chip. Now
the firmware is *more portable* than the library version, not less.

**The lesson.** Cheap Chinese IMU breakouts are a **silicon lottery**.
Never trust the silkscreen. If your vendor library rejects the chip, don't
switch libraries — read the datasheet and just write the four register
writes yourself. Faster and more permanent than fighting library ecosystems.

Also: **the WHO_AM_I byte should be the first thing you print from any
firmware bring-up.** Diagnostic gold, five lines to add, saves hours
downstream.

---

## §7. Silent USB CDC on the S3

**The symptom.** Flashed a fresh sketch onto XIAO ESP32-S3. Serial monitor:
completely blank. No boot text. No `#`. Nothing. Board was clearly running
(LED blinked, reset behavior worked), but `Serial.println("hello world")`
produced zero output over USB-C.

**The debug.** Chased the wrong things first: baud rate mismatch, wrong
port, cable damage. Reflashed twice. Swapped USB cables. Swapped ports.
Same silence.

Actual root cause: the ESP32-S3 has native USB, and the Arduino core needs
a **compile-time flag** to enable Serial-over-USB-CDC on boot. Without it,
the default USB stack doesn't expose a CDC endpoint and every `Serial.write`
goes into the void with **no error, no warning, no log**.

**The fix.** Add to every PIO env:
```
build_flags =
  -DARDUINO_USB_MODE=1
  -DARDUINO_USB_CDC_ON_BOOT=1
```

Silent output → verbose output. Cost: two lines. Time spent finding: one
hour.

**The lesson.** ESP-S3 quirks are unforgiving because they fail silently.
Any board with native USB (as opposed to USB-UART bridge chips like CP210x)
has this kind of trap. Set the two USB flags in every PIO template before
you write a line of firmware.

---

## §6. The wrist-rotation problem: sensor frame vs body frame

**The symptom.** Trained the classifier on labeled reps collected with the
band mounted a specific way. Live testing worked. Then someone put the band
on their other arm — or same arm, different rotation — and the classifier
started firing wrong gestures. Hooks read as jabs. Jabs read as garbage.

**The debug.** The features the classifier used — `ax`, `gx`, `gz` — are
axes in the **IMU chip's own reference frame**. Rotate the chip 90° and
"forward" (+X in training) is now "sideways" (+Z or +Y). The classifier
is looking at the same physical motion through a rotated lens and
correctly reporting a rotated pattern. It's not confused; it's giving
you exactly what you asked for.

**The fix.** Move to **gravity-aligned features**. Low-pass the accel to
estimate the sensor-frame direction of gravity. Decompose every sample
into:
- `a_up` (component along gravity) — invariant to wrist rotation about
  horizontal axes (supination/pronation).
- `a_horiz` (magnitude in horizontal plane) — invariant to yaw around
  vertical.
- `ω_mag` (total gyro magnitude) — orientation-invariant by construction.

Now "punch forward" = `a_horiz` spikes regardless of how the wrist is
rolled. Uppercut = `a_up` positive spike, always. Hook vs jab = discriminate
on `ω_mag`.

**The interesting nuance.** We can't recover absolute *yaw* around gravity
without a magnetometer. But for boxing, the *magnitude* of forward motion
matters, not the compass direction of that motion. A jab thrown facing
north and a jab thrown facing east are both jabs. Gravity gives us enough.

**The lesson.** Sensor-frame features are fragile the moment the sensor
moves relative to the body. If your problem is body-relative (boxing:
"forward relative to me"), you need body-anchored features. Gravity is a
free body-anchor for two axes. The third axis (yaw around gravity) usually
doesn't matter for gestural input.

---

## §5. False positive: wrist twist reads as jab

**The symptom.** After moving to gravity-aligned features, the classifier
still fired jabs when the user rotated their wrist rapidly without moving
their arm at all. Twist your palm from down to up — jab. Not what we want.

**The debug.** The trigger was checking `dynA >= threshold OR wmag >=
threshold`. A pure wrist twist has huge gyro (fast rotation) and moderate
accel (centripetal at the wrist). The `OR` fired on gyro alone. Peak
sanity gate `MIN_PEAK_DYNA` was satisfied by the centripetal accel from
fast rotation.

**The realization.** A jab is fundamentally a **translational** gesture —
the hand goes from A to B in space. A wrist twist is a **rotational**
gesture — the hand stays in place, just rotates. The classifier needed to
distinguish these categories, not just detect "big motion."

**The fix.** Change the trigger from OR to AND on horizontal accel:
```js
if (p.horiz >= JAB_HORIZ_MIN && p.dynA >= MIN_PEAK_DYNA)
```

`horiz` is the gravity-aligned horizontal accel magnitude — invariant
to orientation, tracks actual translational motion. A wrist twist has
low `horiz` (the hand doesn't translate), so it can't fire.

**The lesson.** Every gesture has a "signature category" — translational,
rotational, sustained-still. Your trigger should require **evidence in the
right category**, not just "any big number." Otherwise you'll get
false-positives from motions in the wrong category with big magnitudes.

---

## §4. Puppeteer wanted a specific Chrome binary

**The symptom.** Tried to use the Playwright MCP for visual verification.
It refused with `Chromium distribution 'chrome' is not found at
/opt/google/chrome/chrome`. Suggested `npx playwright install chrome`.
That invocation wanted sudo password. No good.

**The debug.** Discovered we had:
- `/usr/sbin/chromium` (system chromium — works but MCP won't use it)
- `~/.cache/ms-playwright/chromium-1228/chrome-linux64/chrome` (Playwright's
  own bundle — from the earlier `npx playwright install chromium` run)
- No `/opt/google/chrome/chrome` (what MCP wanted)

**The fix.** Bypass the MCP entirely. Install `playwright-core` in a temp
node project. Write a small screenshot script that points explicitly at
the playwright chromium binary:

```js
const browser = await chromium.launch({
  executablePath: '/home/guyonwifi/.cache/ms-playwright/chromium-1228/chrome-linux64/chrome',
  headless: true,
});
```

Works reliably. `NEXT_STEPS.md` has the full recipe.

**The lesson.** MCP browsers assume production-managed installs; local
dev doesn't fit their assumptions. Falling back to `playwright-core` +
explicit `executablePath` is a permanent solution and simpler than fighting
the MCP path expectations.

---

## §3. Menu backdrop reads as "AI-generated"

**The symptom.** After the first Soup Sports pass, the landing menu had a
custom SVG backdrop I'd hand-authored: two clusters of stacked cyan-blue
building rectangles with vine drapes, chrome highway arcs, and a crosswalk-
like water pattern at the bottom. User feedback: **"looks less AI. make it
more unique."**

**The debug.** Compared side-by-side against the reference the user
liked. My scene had:
- Grid-perfect stacked rectangles (AI vibe)
- Repeated identical windows in perfectly regular patterns (AI vibe)
- Zebra-crossing water polygons (dead giveaway — this is what generative
  models over-render)
- Radial gradients doing the work of "buildings"

The reference had:
- Hand-drawn organic shapes with wobbly edges
- Chunky tree stumps as pedestals
- Wildflowers and mushrooms scattered
- No perfect rectangles anywhere

**The fix.** Replace the entire backdrop. Use an `feTurbulence`+
`feDisplacementMap` SVG wobble filter to jitter every filled shape so
edges look hand-drawn. Compose with tree stumps (concentric wood rings),
mushrooms, wildflowers, grass tufts, and two bird silhouettes. Soft
mint-sage grass gradient instead of harsh water blue.

**The lesson.** "AI-generated aesthetic" is real and specific: perfect
geometry, obsessive symmetry, gradient-heavy fills, repeated motifs at
metronomic intervals. To dodge it: **introduce controlled imperfection**
(SVG wobble filter is a cheap way), break symmetry, replace geometric
primitives with organic silhouettes (tree stumps > rectangular buildings),
and add lived-in clutter (flowers, mushrooms, grass).

---

## §2. The mascot cuteness overshoot ("NO UNDO UNDO WHAT HAVE YOU DONE")

**The symptom.** After the first pass of the mascot, a follow-up agent
added tall bat ears, eye sparkles, blush cheeks, a smile, and little feet.
Objectively "cuter." User's reaction was immediate and unambiguous:
**"no undo undo WHAT HAVE YOU DONE."** Reverted.

**The debug.** Not a bug per se — a taste failure. The mascot's design
constraint was "two balls, keep the head good, be simple to make less
fuck-ups." Adding limbs, sparkles, and expressions violated the constraint
without being asked to.

**The fix.** Revert to the sober two-ball design. Add a rule to
`soup/HANDOFF.md` and `CLAUDE.md` documenting the forbidden additions:
**do not add ears, sparkles, feet, smile, blush, eye highlights** unless
explicitly asked.

**The lesson.** Constraint violations that "make things nicer" still lose
if they weren't asked for. When someone gives you a design constraint,
enshrine it in a spec doc so future agents don't re-violate it. Prior
sessions' aesthetic aggression is exactly the kind of thing that gets
enshrined in `CLAUDE.md`'s "what NOT to do" section.

---

## §1. The invisible mascot on the boxing ring (title overlay bug)

**The symptom.** After the boxing polish pass claimed to have integrated
the Soup mascot as the opponent, a Puppeteer screenshot showed the ring
floor, the ropes, and the "SOUP BOXING" title — but no Soup. Where was he?

**The debug.** Bounding-box print showed the mesh existed in world at
`y = 0..2.44m`, `z = -0.80..+0.96` — squarely in front of the camera.
Backface culling ruled out (this bug is described in §11 — Soup was
correctly oriented in the boxing scene, unlike the tennis pass).

Then it clicked: the title overlay covering the ring on load had a
z-index of 70 and a background overlay. It was **supposed to fade out
when the game becomes active**, but "game-active" only got set on connect,
and there was no way to connect during a Puppeteer screenshot. Title
lingered forever, hiding the whole ring, including Soup.

**The fix.** Two changes:
1. Auto-fade the title 2.4s after page load whether or not you connect.
2. `markGestured()` also fades the title on any input, real or dev-key.

Now the title functions as an intro splash, not a permanent occlusion.

**The lesson.** UI states that "should never linger" often do linger in
tests that don't exercise the state transitions. If your screenshot rig
doesn't fire the events that dismiss overlays, the overlays cover the
screenshot. **Test the visible state, not the code path.**

Also: for demo software, prefer auto-fade timers on intro splashes.
Judges pass hardware around, wristbands connect and disconnect, the
"game not connected yet" state should never block them from *seeing*
what the game looks like.

---

## Ongoing: things to add as they come up

- Latency numbers (ESP-NOW round-trip) once measured
- Bomb-detection tuning notes once played with real hardware
- 2-player mode implementation notes (in-flight decision)
- Training data collection quirks from the buddy's session
- Physical cabinet build notes

Every new bug fixed = new §. Every clever solution = worth writing down.

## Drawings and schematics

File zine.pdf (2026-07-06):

# SOUP SPORTS

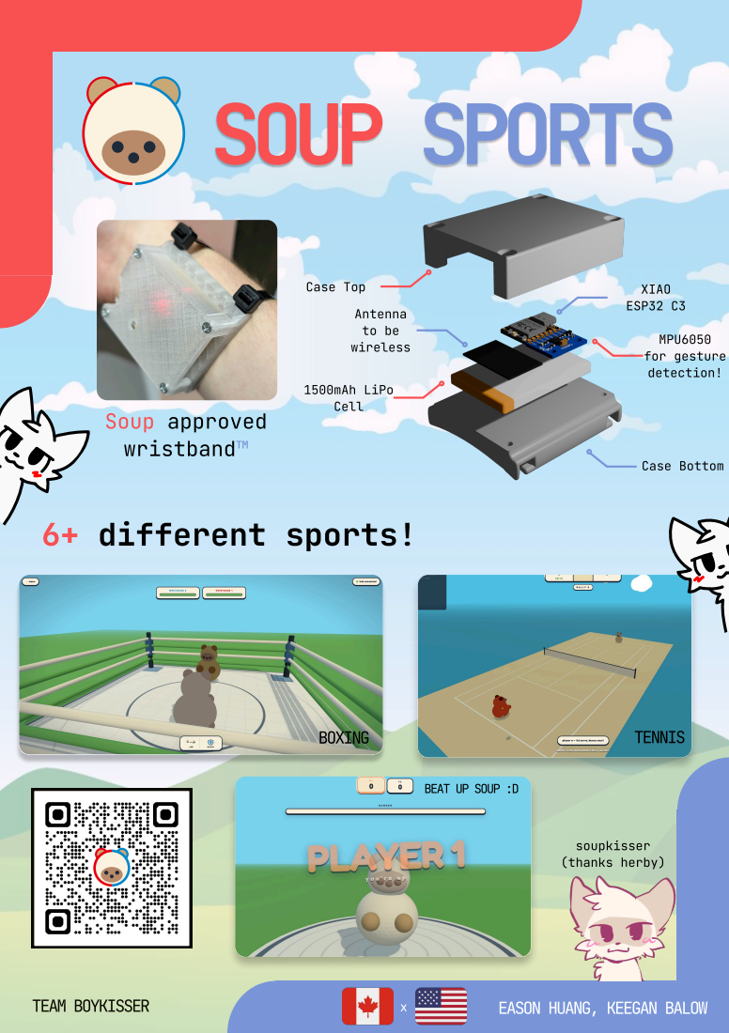
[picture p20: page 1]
Case Top; XIAO; ESP32 C3 Antenna; wireless; MPU6050; for gesture detection!; Soup approved; wristband™; 1500mAh LiPo; Cell; Case Bottom; 6+ different sports!; Boxing; Tennis; soupkisser (thanks herby); Team Boykisser; Eason Huang, Keegan Balow

Beat up soup :D

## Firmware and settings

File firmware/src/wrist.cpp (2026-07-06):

// IMmerseU wrist unit — day 3 wireless build.
//
// Reads MPU6050/6500 at 200Hz, complementary-filters roll/pitch, broadcasts each
// sample as an ASCII CSV line over ESP-NOW. Any dongle on the same channel picks
// it up and writes it to USB serial for the browser to consume.
//
// Compile-time ARM_ID (0 = right arm, 1 = left arm) is prefixed to every line
// so a single dongle can multiplex two wristbands into one serial stream.
//
// Line format (identical to day1 except for the leading ARM_ID):
//   arm,t_us,ax,ay,az,gx,gy,gz,roll,pitch
//   accel m/s², gyro deg/s, roll/pitch degrees.
//
// Set ARM_ID via platformio.ini build_flags (-DARM_ID=0 or 1).

#include <Arduino.h>
#include <WiFi.h>
#include <esp_now.h>
#include <esp_wifi.h>
#include <esp_mac.h>
#include "mpu.h"

// Chip-unique arm identifier derived from the last 2 bytes of the WiFi MAC.
// One firmware image → any wristband. Pairing on the browser side treats the
// integer as opaque and assigns slot A/B by order-of-shake.
static uint32_t arm_id = 0;

// Both wrist units and the dongle must agree on this channel.
static const uint8_t ESPNOW_WIFI_CHANNEL = 1;
static const uint8_t BROADCAST_MAC[6] = {0xFF, 0xFF, 0xFF, 0xFF, 0xFF, 0xFF};

// 200 Hz matches the sample rate the classifier thresholds were tuned
// against. Dropping this even to 100 Hz shifts the noise-floor stats that
// the peak-tracking arm/quiet gates rely on, so the C3 (still at 200 Hz)
// and the S3 (retuned) end up classifying differently. Keep both at 200.
static const uint32_t SAMPLE_HZ = 200;
static const uint32_t SAMPLE_PERIOD_US = 1000000UL / SAMPLE_HZ;
static const float COMP_ALPHA = 0.98f;

static float roll_deg = 0, pitch_deg = 0;
static uint32_t last_us = 0;
static bool espnow_ready = false;

// Fired when a send completes — used only to notice persistent failure.
static uint32_t send_fail_count = 0;
// Newer arduino-esp32 changed the callback signature: mac address is now
// inside wifi_tx_info_t. Keep support for both by using the current one.
static void on_send(const wifi_tx_info_t *info, esp_now_send_status_t status) {
  (void)info;
  if (status != ESP_NOW_SEND_SUCCESS) send_fail_count++;
}

static bool init_espnow() {
  WiFi.mode(WIFI_STA);
  WiFi.disconnect();
  // Turn off WiFi power-save. On the S3 the default modem-sleep drops
  // ~half of a sustained 200 Hz ESP-NOW stream — the C3 doesn't seem to
  // hit this because its power-save timings are different. Cost is a
  // few extra mA of idle current, well worth the reliability.
  WiFi.setSleep(false);
  esp_wifi_set_ps(WIFI_PS_NONE);
  // TX power: 20 dBm default → 14 dBm. Two doublings back from the
  // earlier 11 dBm setting, which was reaching its usable range limit
  // when the wristband sat off-axis to the dongle antenna. 14 dBm keeps
  // most of the LiPo savings while giving ~30 m of margin.
  esp_wifi_set_max_tx_power(56);   // units are 0.25 dBm → 56 = 14 dBm
  esp_wifi_set_channel(ESPNOW_WIFI_CHANNEL, WIFI_SECOND_CHAN_NONE);

  if (esp_now_init() != ESP_OK) return false;
  esp_now_register_send_cb(on_send);

  esp_now_peer_info_t peer = {};
  memcpy(peer.peer_addr, BROADCAST_MAC, 6);
  peer.channel = ESPNOW_WIFI_CHANNEL;
  peer.encrypt = false;
  if (esp_now_add_peer(&peer) != ESP_OK) return false;
  return true;
}

static uint32_t broadcast_count = 0;
static uint32_t next_heartbeat_ms = 0;

// Send an already-formatted line (payload should NOT include trailing '\n' —
// the dongle appends one when it prints).
static void broadcast(const char *payload, size_t len) {
  if (!espnow_ready) return;
  // ESP-NOW max payload is 250 bytes; our lines are ~70 chars — well under.
  esp_now_send(BROADCAST_MAC, (const uint8_t *)payload, len);
}

void setup() {
  Serial.begin(115200);
  uint32_t t0 = millis();
  while (!Serial && (millis() - t0) < 1500) delay(10);

  // Derive our arm_id from the chip's WiFi MAC — unique per board, no
  // compile-time env needed. Last 2 bytes give us a 16-bit slot; collisions
  // are astronomically unlikely at demo scale (~1 in 65k across 2 boards).
  uint8_t mac[6];
  esp_read_mac(mac, ESP_MAC_WIFI_STA);
  arm_id = ((uint32_t)mac[4] << 8) | mac[5];

  uint8_t who = mpu::begin_full_range();
  Serial.printf("# arm=%u mac=%02X:%02X:%02X:%02X:%02X:%02X WHO_AM_I=0x%02X (0x68=MPU6050, 0x70=MPU6500, 0xFF=nothing on bus)\n",
                arm_id, mac[0], mac[1], mac[2], mac[3], mac[4], mac[5], who);

  // I2C bus scan so we can tell "wrong pin" from "no device" at a glance.
  Serial.print("# i2c scan:");
  int found = 0;
  for (uint8_t addr = 1; addr < 127; addr++) {
    Wire.beginTransmission(addr);
    if (Wire.endTransmission() == 0) {
      Serial.printf(" 0x%02X", addr);
      found++;
    }
  }
  Serial.printf("  (%d device%s found)\n", found, found == 1 ? "" : "s");

  espnow_ready = init_espnow();
  Serial.printf("# ESP-NOW %s on channel %d\n",
                espnow_ready ? "ready" : "FAILED",
                ESPNOW_WIFI_CHANNEL);

  // Seed roll/pitch from initial accel so the filter starts sensible.
  int16_t ax_r, ay_r, az_r, gx_r, gy_r, gz_r;
  mpu::read_all(ax_r, ay_r, az_r, gx_r, gy_r, gz_r);
  float ax = ax_r / mpu::ACCEL_LSB_PER_MS2;
  float ay = ay_r / mpu::ACCEL_LSB_PER_MS2;
  float az = az_r / mpu::ACCEL_LSB_PER_MS2;
  roll_deg  = atan2f(ay, az) * 180.0f / PI;
  pitch_deg = atan2f(-ax, sqrtf(ay*ay + az*az)) * 180.0f / PI;

  last_us = micros();
  Serial.printf("# columns: arm,t_us,ax,ay,az,gx,gy,gz,roll,pitch\n");
  Serial.printf("# arm_id is the last two MAC bytes; same firmware runs on every wristband.\n");
}

static char line_buf[96];

void loop() {
  uint32_t now = micros();
  if ((uint32_t)(now - last_us) < SAMPLE_PERIOD_US) return;
  float dt = (now - last_us) * 1e-6f;
  last_us = now;

  int16_t ax_r, ay_r, az_r, gx_r, gy_r, gz_r;
  mpu::read_all(ax_r, ay_r, az_r, gx_r, gy_r, gz_r);

  float ax = ax_r / mpu::ACCEL_LSB_PER_MS2;
  float ay = ay_r / mpu::ACCEL_LSB_PER_MS2;
  float az = az_r / mpu::ACCEL_LSB_PER_MS2;
  float gx = gx_r / mpu::GYRO_LSB_PER_DPS;
  float gy = gy_r / mpu::GYRO_LSB_PER_DPS;
  float gz = gz_r / mpu::GYRO_LSB_PER_DPS;

  float roll_acc  = atan2f(ay, az) * 180.0f / PI;
  float pitch_acc = atan2f(-ax, sqrtf(ay*ay + az*az)) * 180.0f / PI;

  roll_deg  = COMP_ALPHA * (roll_deg  + gx * dt) + (1.0f - COMP_ALPHA) * roll_acc;
  pitch_deg = COMP_ALPHA * (pitch_deg + gy * dt) + (1.0f - COMP_ALPHA) * pitch_acc;

  int n = snprintf(line_buf, sizeof(line_buf),
                   "%u,%lu,%.3f,%.3f,%.3f,%.2f,%.2f,%.2f,%.2f,%.2f",
                   (unsigned)arm_id, (unsigned long)now,
                   ax, ay, az, gx, gy, gz, roll_deg, pitch_deg);
  if (n > 0 && n < (int)sizeof(line_buf)) {
    broadcast(line_buf, (size_t)n);
    broadcast_count++;
  }

  // Heartbeat every 2 s — but ONLY when a USB host has actually opened the
  // CDC port. Otherwise Serial.printf writes into a soft ring buffer that
  // blocks the loop the moment it fills, which starves ESP-NOW broadcasts
  // and shows up as "the S3 wristband takes forever to pair" untethered.
  // The C3's built-in USB-JTAG bridge doesn't have this failure mode.
  uint32_t now_ms = millis();
  if ((int32_t)(now_ms - next_heartbeat_ms) >= 0) {
    next_heartbeat_ms = now_ms + 2000;
    if (Serial) {
      Serial.printf("# wrist alive arm=%u sent=%lu fails=%lu\n",
                    (unsigned)arm_id,
                    (unsigned long)broadcast_count,
                    (unsigned long)send_fail_count);
    }
  }
}

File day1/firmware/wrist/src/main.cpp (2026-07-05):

// IMmerseU — wrist unit, day 1
// Streams raw IMU + complementary-filter roll/pitch as CSV over USB serial.
// Works with both MPU6050 (WHO_AM_I=0x68) and MPU6500 (WHO_AM_I=0x70) — the
// GY-521 boards on the market ship with either. Register map is compatible for
// basic accel+gyro so we drive it directly with Wire instead of a vendor lib.
//
// Wiring (XIAO ESP32-S3):
//   SDA -> D4 (GPIO5), SCL -> D5 (GPIO6), VCC -> 3V3, GND -> GND, AD0 floating.
//
// Output (CSV, one line/sample @ 200Hz):
//   t_us,ax,ay,az,gx,gy,gz,roll,pitch
//   accel m/s², gyro deg/s, roll/pitch degrees.

#include <Arduino.h>
#include <Wire.h>

static const uint8_t MPU_ADDR = 0x68;
// Register map (shared between MPU6050 / MPU6500).
static const uint8_t REG_SMPLRT_DIV   = 0x19;
static const uint8_t REG_CONFIG       = 0x1A; // gyro DLPF
static const uint8_t REG_GYRO_CONFIG  = 0x1B; // FS_SEL
static const uint8_t REG_ACCEL_CONFIG = 0x1C; // AFS_SEL
static const uint8_t REG_ACCEL_CONFIG2= 0x1D; // MPU6500 accel DLPF (ignored by 6050)
static const uint8_t REG_ACCEL_XOUT_H = 0x3B;
static const uint8_t REG_PWR_MGMT_1   = 0x6B;
static const uint8_t REG_WHO_AM_I     = 0x75;

// ±16g -> 2048 LSB/g; ±2000 dps -> 16.4 LSB/(dps).
static const float ACCEL_LSB_PER_MS2 = 2048.0f / 9.80665f;
static const float GYRO_LSB_PER_DPS  = 16.4f;

static const uint32_t SAMPLE_HZ = 200;
static const uint32_t SAMPLE_PERIOD_US = 1000000UL / SAMPLE_HZ;
static const float COMP_ALPHA = 0.98f;

static float roll_deg = 0, pitch_deg = 0;
static uint32_t last_us = 0;

static void wr(uint8_t reg, uint8_t val) {
  Wire.beginTransmission(MPU_ADDR);
  Wire.write(reg); Wire.write(val);
  Wire.endTransmission();
}
static uint8_t rd(uint8_t reg) {
  Wire.beginTransmission(MPU_ADDR);
  Wire.write(reg);
  Wire.endTransmission(false);
  Wire.requestFrom(MPU_ADDR, (uint8_t)1);
  return Wire.available() ? Wire.read() : 0xFF;
}

// Read 14 bytes (accel xyz, temp, gyro xyz) starting at ACCEL_XOUT_H.
static void read_all(int16_t &ax, int16_t &ay, int16_t &az,
                     int16_t &gx, int16_t &gy, int16_t &gz) {
  Wire.beginTransmission(MPU_ADDR);
  Wire.write(REG_ACCEL_XOUT_H);
  Wire.endTransmission(false);
  Wire.requestFrom(MPU_ADDR, (uint8_t)14);
  uint8_t b[14];
  for (int i = 0; i < 14 && Wire.available(); i++) b[i] = Wire.read();
  ax = (int16_t)((b[0]  << 8) | b[1]);
  ay = (int16_t)((b[2]  << 8) | b[3]);
  az = (int16_t)((b[4]  << 8) | b[5]);
  // b[6..7] = temp — skip
  gx = (int16_t)((b[8]  << 8) | b[9]);
  gy = (int16_t)((b[10] << 8) | b[11]);
  gz = (int16_t)((b[12] << 8) | b[13]);
}

void setup() {
  Serial.begin(115200);
  uint32_t t0 = millis();
  while (!Serial && (millis() - t0) < 1500) delay(10);

  Wire.begin();
  Wire.setClock(400000);

  uint8_t who = rd(REG_WHO_AM_I);
  Serial.printf("# WHO_AM_I = 0x%02X (0x68=MPU6050, 0x70=MPU6500, 0x71=MPU9250)\n", who);
  if (who != 0x68 && who != 0x70 && who != 0x71 && who != 0x73) {
    Serial.println("# WARN: unknown chip; register writes will still be attempted.");
  }

  wr(REG_PWR_MGMT_1, 0x80); delay(100);       // reset
  wr(REG_PWR_MGMT_1, 0x01); delay(20);        // wake, PLL on gyro X
  wr(REG_SMPLRT_DIV, 0x00);                   // 1kHz internal / (1+0)
  wr(REG_CONFIG,       0x02);                 // gyro DLPF ~92 Hz — keeps punch edges
  wr(REG_GYRO_CONFIG,  0x18);                 // ±2000 dps
  wr(REG_ACCEL_CONFIG, 0x18);                 // ±16 g
  wr(REG_ACCEL_CONFIG2,0x02);                 // accel DLPF ~92 Hz (MPU6500 only; 6050 ignores)

  // Seed filter from initial accel.
  int16_t ax_r, ay_r, az_r, gx_r, gy_r, gz_r;
  read_all(ax_r, ay_r, az_r, gx_r, gy_r, gz_r);
  float ax = ax_r / ACCEL_LSB_PER_MS2;
  float ay = ay_r / ACCEL_LSB_PER_MS2;
  float az = az_r / ACCEL_LSB_PER_MS2;
  roll_deg  = atan2f(ay, az) * 180.0f / PI;
  pitch_deg = atan2f(-ax, sqrtf(ay*ay + az*az)) * 180.0f / PI;

  last_us = micros();
  Serial.println("# IMmerseU wrist feature stream");
  Serial.println("# columns: t_us,ax,ay,az,gx,gy,gz,roll,pitch");
}

void loop() {
  uint32_t now = micros();
  if ((uint32_t)(now - last_us) < SAMPLE_PERIOD_US) return;
  float dt = (now - last_us) * 1e-6f;
  last_us = now;

  int16_t ax_r, ay_r, az_r, gx_r, gy_r, gz_r;
  read_all(ax_r, ay_r, az_r, gx_r, gy_r, gz_r);

  float ax = ax_r / ACCEL_LSB_PER_MS2;
  float ay = ay_r / ACCEL_LSB_PER_MS2;
  float az = az_r / ACCEL_LSB_PER_MS2;
  float gx = gx_r / GYRO_LSB_PER_DPS;
  float gy = gy_r / GYRO_LSB_PER_DPS;
  float gz = gz_r / GYRO_LSB_PER_DPS;

  float roll_acc  = atan2f(ay, az) * 180.0f / PI;
  float pitch_acc = atan2f(-ax, sqrtf(ay*ay + az*az)) * 180.0f / PI;

  roll_deg  = COMP_ALPHA * (roll_deg  + gx * dt) + (1.0f - COMP_ALPHA) * roll_acc;
  pitch_deg = COMP_ALPHA * (pitch_deg + gy * dt) + (1.0f - COMP_ALPHA) * pitch_acc;

  Serial.printf("%lu,%.3f,%.3f,%.3f,%.2f,%.2f,%.2f,%.2f,%.2f\n",
                (unsigned long)now, ax, ay, az, gx, gy, gz, roll_deg, pitch_deg);
}

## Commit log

2026-07-05 day3 wireless boxing prototype + CLAUDE.md orientation
    - day1: original wired snapshot (USB CSV streaming wrist, Three.js boxing
    scene, Python auto-trigger collector + JS replay harness)
    - day3: wireless build — ESP-NOW broadcaster wristbands + XIAO dongle
    receiver, 3 PIO envs share one src/ tree. Browser gains ArmDispatcher
    so left+right bands multiplex through one serial connection into
    per-arm classifier instances. Collector accepts arm-prefixed CSV
    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
    [hook.csv, jab.csv, soup.scad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]
2026-07-05 Soup Sports — four-game arcade with mascot integration
    - Rebrand: sky-cyan + cream palette, post-apocalyptic Wii Sports vibe. New
    landing menu at app/index.html with animated clouds, ruin silhouettes,
    water at the bottom. All four games share the palette + chunky
    cream-pill button treatment.
    - day3/app/ now has four playable minigames:
    boxing.html — jab/hook/uppercut vs opponent Soup, KO ends the round
    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
    [soup.stl]
2026-07-05 Real 3D Soup on the landing page
    Replaces the CSS-blob logo hero with a live GLTF-loaded mascot rendered
    in a small transparent Three.js canvas between the title and the game
    cards. Idle bob + squish + head sway, wave every ~5.5s via the 'paws'
    node rotation. Falls back to a cream sphere if the GLB fails to load
    so the hero area isn't empty.
2026-07-05 Painterly ruin backdrop + polish landings + Soup Bomb slot
    - index.html rewrite: replaced abstract radial-gradient ruins with a
    full SVG scene matching the promo art — flooded city silhouettes with
    green vine overlays on both sides, curved chrome highway arcs, small
    background city, zebra-crossing lanes vanishing into cyan water with
    foam ripples, five puffy drifting clouds.
    - Hero mascot now falls back to an immediately-visible CSS placeholder
    (a cream blob with two dot eyes bobbing) if the GLB hasn't loaded yet,
    so the hero area is never empty. Placeholder fades out once the real
    Soup joins the scene.
    - Added a 5th menu card: Soup Bomb (push-your-luck party game). Card
    po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
2026-07-05 5th game + tennis + boxing polish + fresh screenshot pass
    - punch_bomb.html — push-your-luck party game. Punch Soup, bank with a
    1-second hold-still gesture. Random hidden bomb count per turn.
    2-4 player rotation, 5-round match. Fullscreen BOOM cartoon on
    detonation. All edge cases handled (single player rejected, tie
    breaks, restart clean).
    - boxing.html polish landing: title auto-fades so opponent is visible,
    removed stray Y-flip that was hiding Soup, ropes+posts chunkier,
    brighter sky, vine-green horizon apron, gesture tutorial cards
    (jab/hook/uppercut), hit sparks, camera FOV zoom-punch on hit,
    full KO celebration (flash + banner + 90 confetti), first-person
    gloves p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
2026-07-05 Menu: hand-drawn meadow backdrop + compact layout
    Ditched the crosswalk/city-ruin SVG (read as AI-generated). Replaced
    with a cozy game-hub scene: soft mint-sage grass hills with hand-drawn
    wobble filter, two chunky tree stumps with wood rings + ivy, scattered
    grass tufts, wildflowers (pink daisies + fly-away mushrooms), two bird
    silhouettes in the sky. New palette (softer sky, warm woody browns).
    Layout compressed to fit in one viewport without scroll:
    - Hero clamp'd smaller (120px..180px)
    - H1 down to clamp(36px..68px)
    - Card grid tighter with smaller minmax + gap
    - Card padding + icon + font sizes reduced
    - Header + title-block margins tightened
2026-07-05 NEXT_STEPS.md — handoff doc for the next session
    Captures: current state (5 games shipped + polished), in-flight open
    questions (2P modes, JAB-only classifier waiting on training data,
    menu overflow just fixed, hardware side untouched), Soup Sports palette
    + mascot loading pattern quick-ref, the working Puppeteer verification
    recipe, recent commit history, immediate priority queue.
    Companion to CLAUDE.md which stays evergreen — this file rolls forward
    as context.
2026-07-05 Added files for prints
    [Top Watch Top.stl]
2026-07-05 DEVLOG.md — running technical war stories, presentation-ready
    Eleven entries covering: the MPU6500-clone-as-MPU6050 register bait-and-
    switch, ARDUINO_USB_CDC_ON_BOOT silent-serial trap, wrist-rotation
    gravity-alignment insight, wrist-twist false-positive fix, Puppeteer
    executablePath workaround, four polish agents in parallel, bowling
    camera framing multi-bug stack, tennis mascot backface-culling from a
    double Y-flip, boxing invisible-mascot-from-lingering-title-overlay,
    mascot cuteness overshoot and revert, AI-aesthetic-vs-hand-drawn menu
    backdrop. Each entry has Symptom / Debug / Fix / Lesson so it doubles
    as demo-day talk material.
    CLAUDE.md and NEXT_STEPS.md updated to describe the d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
2026-07-05 Menu: put distant ruins behind the meadow
    User wanted to keep the cozy grass/stump foreground but bring back
    the flooded city silhouette that was in the earlier design. Layered
    in as small hazy blue-teal buildings + ivy drapes on the horizon,
    sitting behind the hill silhouettes so it reads as "distant ruins
    across the plain."
    Includes: left ruin cluster, small distant city, right cluster, two
    thin chrome arcs, a thin water reflection tint at the ruin base line.
    All under a shared wobble filter for the hand-drawn feel.
2026-07-05 Fable UI audit and redesign across all six pages
    The big functional find: the same soup.rotation.y bug documented in
    DEVLOG §11 was also present in three more files. The menu hero, the
    bowling bowler at the near end of the lane, and the baseball pitcher
    were all invisible for the same reason. All three now render.
    System applied everywhere:
    - one .ss-btn treatment (cream pill, ink border, 0 3px 0 shadow)
    - menu link top-left, hub pill top-right (connect + status merged
    into one control; the separate status pill went away, which also
    fixed the connect button vanishing when dev keys fired game-active)
    - score HUD top-center, dropping to top:64px under 640px
    - lowercase-voice prompts as p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
2026-07-05 Boxing: Soup vs Soup with per-gesture animations
    Camera flipped to over-the-shoulder third person, first-person hands
    and their whole makeArm factory removed cleanly. Player Soup foreground
    at (0.35, 0, 1.4), opponent at (0, 0, -2.4). Both mascots wrap in a
    fighter rig `g > lean > soup` so all animation lives on `lean` and the
    `paws` node, leaving the canonical rotation.x flip untouched.
    Player animations, each with its own envelope and lean:
    - jab 280ms, paws punch forward with a small lunge, snap back
    - hook 360ms, three-phase wind-up whip-across recover, paws describe
    an arc, body rotates through the swing
    - uppercut 360ms, load with knees bent and paws down, drive with
    vertical stre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
    [hook.csv, jab.csv]
2026-07-05 updated names to try to get 4 printed
    [Top Watch Top(PLEASE PRINT 4 OF THESE).stl]
2026-07-05 Bank the demo state: rebrand, tune-log, auto-connect, live tuning
    - Rebrand: Soup Sports → Soup Games. Straight mechanical rename of the
    brand text, page titles, and one CSS comment across all six pages.
    Visuals unchanged. Awaiting future SVGs before touching narrative
    copy or the meadow backdrop.
    - Auto-connect on every page: bowling, tennis, baseball, punch_bomb now
    match boxing. serial.js's autoOpenSerial() runs at load, if the hub
    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
    [hook.csv, jab.csv, uppercut.csv]
2026-07-05 Retune classifier against fresh day3 training data
    New data captured with the wristband at a mild off-axis angle relative
    to the forearm. Full retune from scratch:
    - Discriminators rebuilt from the actual per-rep peaks. Idle.csv used as
    the ground-truth gravity vector for the whole set (auto-triggered
    recordings center on peak motion and never contain true rest, so we
    can't derive gravity from the punch data itself).
    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
2026-07-06 Soup Ninja + UX polish + pitch docs
    - New game: Soup Ninja (fruit ninja lookalike). Slice = single swing peak,
    bombs slime you out, PvP splits the arena L/R. Replaces baseball on the
    menu (baseball.html left on disk).
    - UX polish across all games: play-again pill on boxing KO, bowl-again
    banner on bowling gameover, rally-pill restyle in tennis, pair-hint
    moved into HUD flow, mobile score-card scaling, Fredoka/Nunito web
    fonts now actually load.
    - Pairing menu: 'shake me' hint when an unclaimed wristband broadcasts
    quietly, letter blob wiggles to cue.
    - Pitch docs: PITCH_TECHNICAL.md (arch + signal processing + multi-
    controller story), PITCH_TALK_TRACK.md (90-second demo pitch)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
2026-07-06 SFX, boxing tutorial timing, bowling clipping, ninja polish
    - sfx.js: Web Audio API sound bank. Punch/KO for boxing, ball roll +
    pin hits + strike/gutter for bowling, rally + serve for tennis,
    slice + bomb-slash for ninja, pair-chime + click for menu.
    - Boxing tutorial: shows immediately, held minimum 4.5s so first-time
    players actually read the three moves before it fades. Uppercut
    icon rebuilt as a clean up-arrow (no more stacked orange glove).
    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
2026-07-06 PvP across boxing/bowling/tennis + universal wristband firmware
    - Boxing PvP: routes arm-per-player via pairing.js, HP now actually decrements,
    KO fires for either loser, camera follows the crumpler
    - Bowling PvP: split scoreboard, alternating turns, per-player frame state
    - Tennis PvP: rally state machine, real tennis scoring (love/15/30/40/deuce,
    first-to-3 games), forehand/backhand from sign(gz) at peak
    - Universal wristband firmware: arm_id derived from chip MAC at boot, one
    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
    [block.csv, hook.csv, idle.csv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]
2026-07-06 Demo build: 6 games, jab+block classifier, PvP everywhere, polish pass
    Games:
    - Boxing PvP: jab + block, red/blue mascots, intro labels, HP-only HUD
    - Bowling PvP kept (currently hidden from menu, file preserved)
    - Tennis PvP: real-spec 23.77x8.23m court, 0.914m net, service boxes,
    double-fault, love/15/30/40/deuce, first-to-1-set. Ball guaranteed to
    clear net via arc iterator (40 rounds, 3s cap). Bounce-once rule.
    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
2026-07-06 Repo cleanup + tennis rewrite
    Repo:
    - Flatten day3/ to repo root: app/, firmware/, tools/, GESTURES.md
    - Archive personal + internal files to _archive/: CLAUDE.md, DEVLOG.md,
    JOURNEY.md, PITCH_*.md, USER_FLOW.md, NEXT_STEPS.md, IDEA.md, day1/,
    singleplayer/, blink/, soup/, and old dev screenshots
    - 3D Prints/ renamed to enclosure/
    - README screenshots moved to docs/img/ with proper names
    - README rewritten with the new repo layout section
    Tennis:
    - Rewrote as pure timing-based. No ballistic solver, no gravity, no
    bounce, no net collision. Ball flies via fixed-duration parabolic
    lerp. Swing inside the hit window = successful return; miss = point
    to opponent.
    - Hit window scales wit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
    [Top Watch Top(PLEASE PRINT 4 OF THESE).stl, block.csv, hook.csv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]
2026-07-06 uploaded cad files and updated readme
    [Top Watch Base.step, Top Watch Top(PLEASE PRINT 4 OF THESE).stl, Top Watch Top.step]
2026-07-06 MWAHAHA WE ARE DONE
    [wristband.kicad_sch]
